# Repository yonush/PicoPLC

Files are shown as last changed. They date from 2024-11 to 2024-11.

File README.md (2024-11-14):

# The RP2040/RP2350 PLC - picoPLC

This repo is the design files and sample code for the diy PLC "picoPLC". It is robust PLC using the Raspberry Pi microcontroller boards as the main controller. Supported boards:

- Raspberry Pico (RP2040)
- Raspberry Pico W (RP2040)
- Raspberry Pico 2 (RP2350 using ARM cores)
- Raspberry Pico 2 (RP2350 using RISC-V cores)

Other RP2040/RP2350 boards that follow the Raspberry Pico pinout are also supported

The picoPLC has the following features 

- 5-12V power (connections are 12V tolerant. NO 24V)
- Has a 3.3, 5V and 12V breakout (if 12V power used)
- 8 digital outputs using relays
- 8 digital inputs
- 3 analog inputs
- 2 analog outputs (PWM or analog)
- 1 1-wire (Dallas/DHT22/DHT11, etc)
- 1 I2C, SPI, UART (shared pins)

The picoPLC was originally designed to use the [OpenPLC](https://autonomylogic.com/) soft PLC but it has been tested with C/C++, MicroPython and CircuitPython. Sample code for the CircuitPython has been included. The demo CircuitPython code uses [pyRTOS](https://github.com/Rybec/pyRTOS) as a proof of concept for some asynchronous tasks. 

### Mutli-core operation

Multi-core operation is not supported in CircuitPython but is available using MicroPython. Multi-core operation can be achieved in OpenPLC by editing the HAL source files and using the Mbed OS toolchain. More details on Using OpenPLC can be found in [OpenPLC Notes](OpenPLC_notes.md)

### TODO
- :white_check_mark: Fix PWM range and frequency (rev2)
- :white_large_square: Revision 3 to support 24V inputs
- :white_large_square: Revision 3 to include opto-isolaters on the inputs
- :white_large_square: Additional sample code

## Schematic
Schematic was created in KiCad. The BoM can be found in **Schematic and PCB** folder. The image below is only of page 1. Full schematic can be found in the folder.

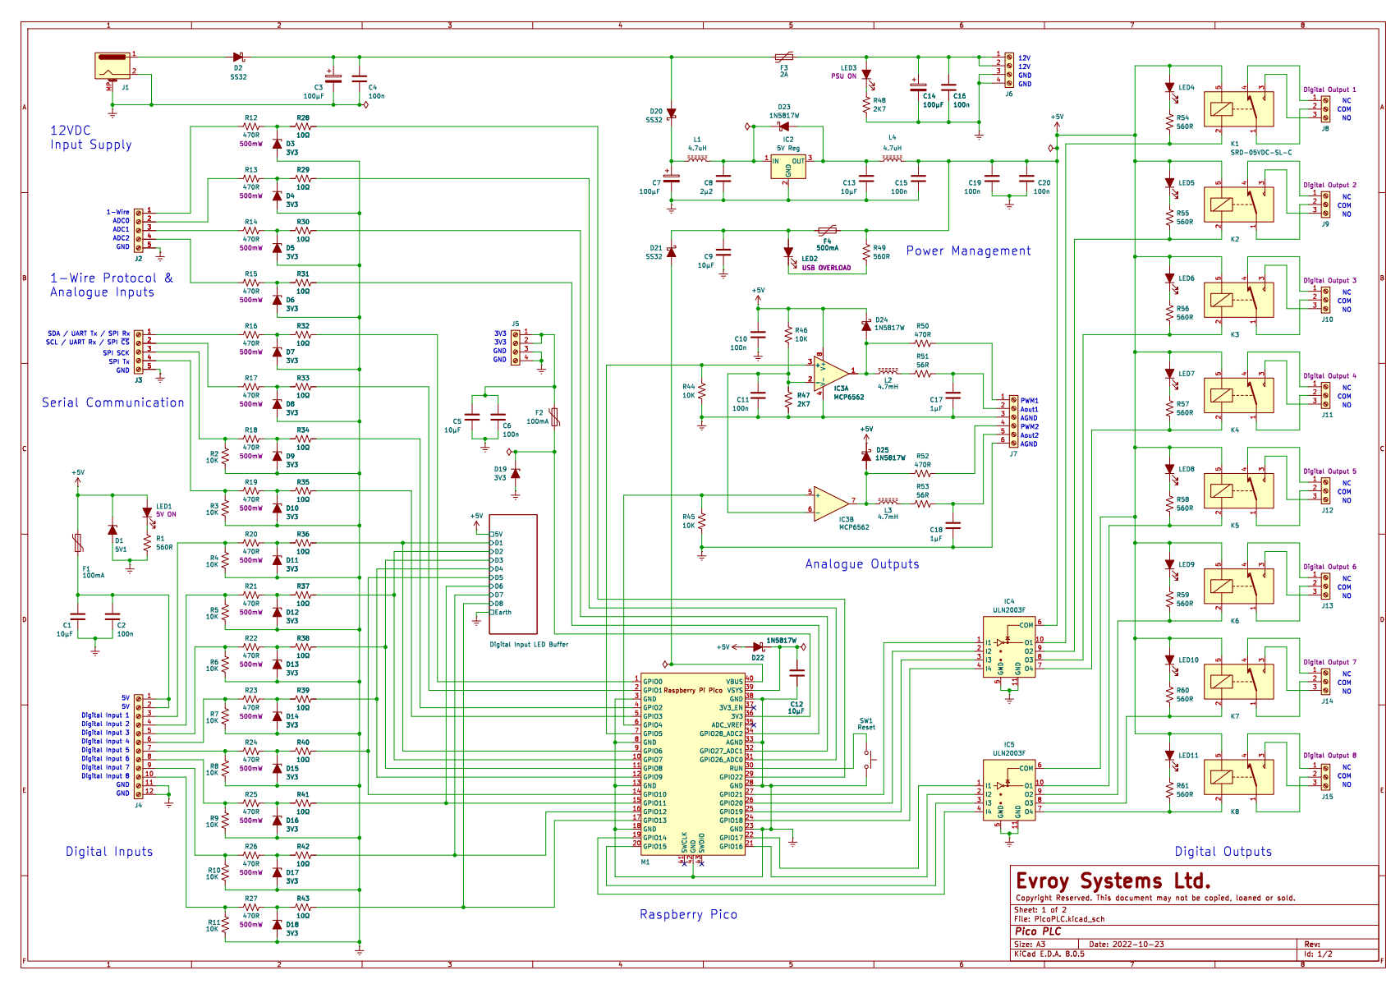
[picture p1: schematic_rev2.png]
schematic


### Physical device

**Revison 1**
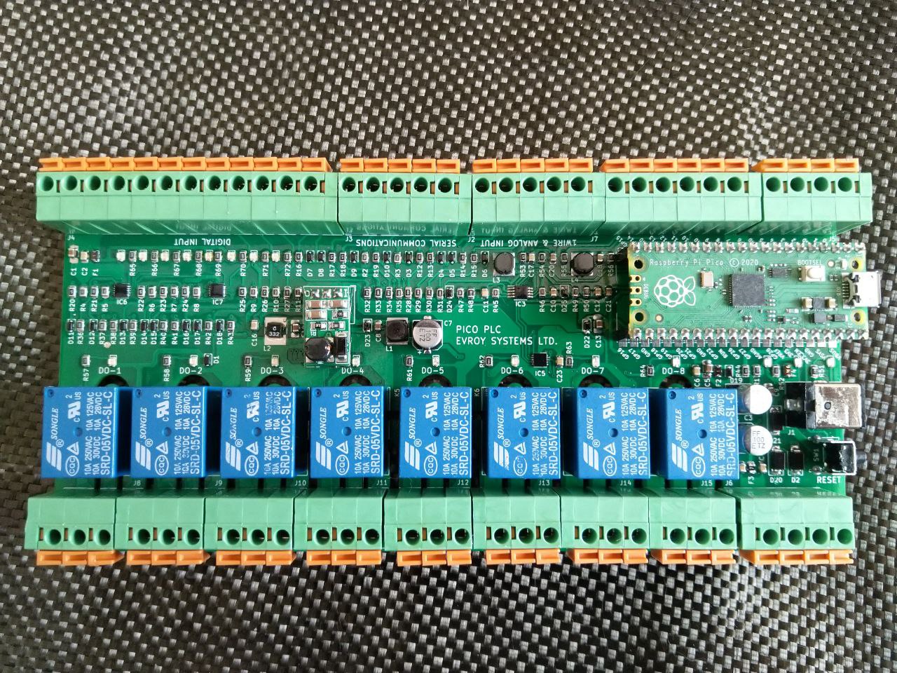
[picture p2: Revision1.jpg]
revision_1


**Revison 2**
reviison_2

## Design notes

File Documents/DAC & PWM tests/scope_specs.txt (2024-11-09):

Model:DS2302A
Manufacturer:RIGOL TECHNOLOGIES
Hardware Ver:2.0
Firmware:00.03.05.00.01
Status:
L:[HEX] 0000 0000	[BIN] 0000 0000 0000 0000 0000 0000 0000 0000
H:[HEX] 0000 0000	[BIN] 0000 0000 0000 0000 0000 0000 0000 0000
2023:2:6 20:48:43

	DSO Vertical System 
CH1:On
Scale:1.000e+03mV/
Position:-2.000e+03mV
Coupling:DC
Invert:Off
Bandwidth Limit:OFF
Probe Ratio:10X
Impedance:1M
Unit:V
User Cal:0ps

CH2:Off
Scale:1.000e+04mV/
Position:6.750e+04mV
Coupling:DC
Invert:Off
Bandwidth Limit:OFF
Probe Ratio:50X
Impedance:1M
Unit:V
User Cal:0ps

	DSO Horizontal System
Delay:Off
Time Vernier:Off
Time Mode:YT
Time Scale:1.000000e-03s
Delay Time Scale:5.000000e-04s
Time Offset:0.000000e+00s
Delay Time Offset:7.000000e-04s

	DSO Acquire System
Acquire Mode:Normal
Memory Depth:14000000
Average Num:2
Sampling Rate:1.000e+09

	DSO Normal Trigger System
Trigger Mode:Edge
Trigger Source:CH1
Trigger Sweep:Single
Trigger Coupling:DC
Trigger Noise Reject:Off
Trigger HoldOff:1.000000e-07s
CH1 Level:5.070000V
CH2 Level:-100.100000V
Ext Level:0.000000V
Trigger Edge Slope:Rising
Pulse Condition:Negative More Less
Pulse High:1.911204e-02s
Pulse Low:1.391204e-02s
Runt Polarity:Negative
Runt Condition:More
Windows Type:Alternate
Windows Pos:Enter
Window Time:1.000e-06s
NCycle Edge:Rise
NCycle Time:1.000e-07s
NCycle Num:2
Slope Condition:Positive More
Slope High:2.000e-06s
Slope Low:1.000e-06s
Slope Level1:1.020000V
Slope Level2:-4.000000V
Video Polarity:Negative
Video Sync:All Lines
Video Standard:NTSC
Video Line:1
Pattern HL:[HEX] 0000 0000	[BIN] 0000 0000 0000 0000 0000 0000 0000 0000
Pattern Mask:[HEX] 0000 0000	[BIN] 0000 0000 0000 0000 0000 0000 0000 0000
Pattern Edge:[HEX] 0000 0000	[BIN] 0000 0000 0000 0000 0000 0000 0000 0000
Pattern Edge Mask:[HEX] 0000 0000	[BIN] 0000 0000 0000 0000 0000 0000 0000 0000
Delay A:CH1
Delay B:CH2
Delay A Slope:Rising
Delay B Slope:Rising
Delay Range:More
Delay High:2.000e-06s
Delay Low:1.000e-06s
TimeOut Slope:Rising
TimeOut:1.000e-06s
Duration Type:More
Dura. High:2.000e-06s
Dura. Low:1.000e-06s
Setup/Hold Clk:CH1
Setup/Hold Data:CH2
Setup/Hold Slope:Rising
Setup/Hold Patt.:H
Setup/Hold Type:Setup
Setup Time:5.000e-08s
Hold Time:5.000e-08s

	DSO Advanced Trigger System
I2C Trigger
Clock Source:CH1
Data Source:CH2
I2C Type:Start
Address:1
Data Qualifier:Equal
Address Qualifier:Equal
Direction:Read
Address Length:7
Byte Length:1

Data:[HEX] 0000 0000 0000 0000	[BIN] 0000 0000 0000 0000 0000 0000 0000 0000 0000 0000 0000 0000 0000 0000 0000 0000
Mask:[HEX] 0000 0000 0000 0000	[BIN] 0000 0000 0000 0000 0000 0000 0000 0000 0000 0000 0000 0000 0000 0000 0000 0000

RS232 Trigger
RS232 Source:CH1
RS232 Type:Frame Start
RS232 Stop Bit:1
RS232 Parity:None
RS232 Data Bit:8
RS232 Baudrate:9600
RS232 User Baudrate:9600
RS232 Data:70

SPI Trigger
SCLK:CH1
SDA:CH2
Mode:Timeout
Edge:Rise
Timeout:1.000e-06
Data Length:8
Data:[HEX] 0000 0000	[BIN] 0000 0000 0000 0000 0000 0000 0000 0000
Mask:[HEX] 0000 0000	[BIN] 0000 0000 0000 0000 0000 0000 0000 0000

CAN Trigger
CAN Type:Start
Frame:Data
Signal:Rx
Speed:10K
User Speed(KB):50.000000
Sampling Point:50
Error:Bit Fill
Standard ID:true
Setting ID:false
Data Length:1
ID:1
Data:[HEX] 0000 0000 0000 0000	[BIN] 0000 0000 0000 0000 0000 0000 0000 0000 0000 0000 0000 0000 0000 0000 0000 0000
Data:[HEX] 0000 0000 0000 0000	[BIN] 0000 0000 0000 0000 0000 0000 0000 0000 0000 0000 0000 0000 0000 0000 0000 0000

USB Trigger
Type:SOP
DP:CH1
DN:CH2
Speed:Low

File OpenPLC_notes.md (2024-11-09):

# Notes on using OpenPLC with the Raspberry Pico 1, Pico W and Pico 2

Other variants of the pico board work too. This may require changes or additions to the editor\arduino\examples\Baremetal\hals.json file.

An additional .cpp & .hal file might be requried in the editor\arduino\src\hal folder to support new pico hardware.

## OpenPLC hal definitions for the Pico 1, Pico 1 W, and Pico 2

The Hardard 3 cores in the Pico 2 are also supported by OpenPLC

**Note, the mapping of the digital out pins in OpenPLC differ to the physical pins on the picoPLC.**

``` json
  "Raspberry Pico": {
    "core": "rp2040:rp2040",
    "default_ain": "26, 27, 28",
    "default_aout": "4,5",
    "default_din": "6, 7, 8, 9, 10, 11, 12, 13",
    "default_dout": "14, 15, 16, 17, 18, 19, 20, 21",
    "last_update": 0,
    "platform": "rp2040:rp2040:rpipico",
    "source": "rp2040pico.cpp",
    "version": "4.2.0"
  },
  "Raspberry Pico 2": {
    "core": "rp2040:rp2040",
    "default_ain": "26, 27, 28",
    "default_aout": "4,5",
    "default_din": "6, 7, 8, 9, 10, 11, 12, 13",
    "default_dout": "14, 15, 16, 17, 18, 19, 20, 21",
    "last_update": 0,
    "platform": "rp2040:rp2040:rpipico2",
    "source": "rp2040pico.cpp",
    "version": "4.2.0"
  },
  "Raspberry Pico 2 (RISCV)": {
    "arch": "riscv",
    "core": "rp2040:rp2040",
    "default_ain": "26, 27, 28",
    "default_aout": "4,5",
    "default_din": "6, 7, 8, 9, 10, 11, 12, 13",
    "default_dout": "14, 15, 16, 17, 18, 19, 20, 21",
    "last_update": 0,
    "platform": "rp2040:rp2040:rpipico2:arch=riscv",
    "source": "rp2040pico.cpp",
    "version": "4.2.0"
  },
  "Raspberry Pico W": {
    "core": "rp2040:rp2040",
    "default_ain": "26, 27, 28",
    "default_aout": "4,5",
    "default_din": "6, 7, 8, 9, 10, 11, 12, 13",
    "default_dout": "14, 15, 16, 17, 18, 19, 20, 21",
    "define": "BOARD_PICOW",
    "last_update": 0,
    "platform": "rp2040:rp2040:rpipicow",
    "source": "rp2040pico.cpp",
    "version": "4.2.0"
  },
```
## RP2040/RP2350 notes for the picoPLC pinout

Raspberry Pi Pico PINOUT (RP2040)
Digital In:  6, 7 ,8, 9, 10, 11, 12, 13     (%IX0.0 - %IX0.7)
Digital Out: 21, 20, 19, 18, 17, 16, 15, 14 (%QX0.0 - %QX0.7) (this is opposite to the list in OpenPLC)
Analog In: A1, A2, A3 (26,27,28)            (%IW0 - %IW2)
Analog Out: 4,5                             (%QW0 - %QW1)

The onboard LED (GPIO25) is not used but can be accessed from OpenPLC for the Pico or Pico 2 NOT the Pico W!!

## updated modbus addressing

The Modbus address space was expanded to include memory locations %MW (16-bit words) %MD (32-bit double words) and %ML (64-bit long words). These extra memory locations are available as Modbus holding registers. Here is the breakdown of the address space:
 
%QW0 - %QW31 -> Modbus holding registers 0 - 31
%MW0 - %MW19 -> Modbus holding registers 32 - 51
%MD0 - %MD19 -> Modbus holding registers 52 - 91 (each MD takes up two Modbus registers)
%ML0 - %ML19 -> Modbus holding registers 92 - 171 (each ML takes up four Modbus registers)
 
This means can also read/write REAL and LREAL variables on Modbus registers. You can locate the REAL variable on any %MD location or LREAL variable on any %ML location. Larger integers are also possible using these expanded locations. On the modbus master side, you just need to configure your application to concatenate Modbus registers to form an IEEE float (two registers in case of REAL or four registers in case of LREAL).

### Typical Modbus ranges
Discrete Output Coils      00001-09999
Discrete Input Contacts    10001-19999
Analog Input Registers     30001-39999
Holding Registers          40001-49999

The following location prefixes are supported:
    I for input
    Q for output
    M for memory

The following size prefixes are supported:

    X for bit (1 bit)
    B for byte (8 bits)
    W for word (16 bits)
    D for double word (32 bits)
    L for long word (64 bits)

The following are invalid examples of PLC addresses in OpenPLC for the stated reason:

    %IX0.8 The least significant index is greater than 7.
    %QX0.0.1 Three part hierarchy is not permitted address.
    %IB1.1 Two part hierarchy is only permitted for X data size.

### Modbus functions

OpenPLC supports the following Modbus functions:

    Read discrete output coil (0x01)
    Write discrete output coil (0x05)
    Write multiple discrete output coils (0x0F)
    Read discrete input contacts (0x02)
    Read analog input registers (0x04)
    Read analog output holding registers (0x03)
    Write analog output holding register (0x06)
    Write multiple analog output registers (0x10)

Discrete output coil and discrete input contact binding are based on the the two-part PLC address, without unused Modbus data addresses. The least-significant part of the PLC address has a range 0 to 7, therefore, a little math is needed to translate between PLC addresses and Modbus data addresses. Given the Modbus data address, the PLC address is determined as:

    msp := int(modbus_data_address / 8)
    lsp := modbus_data_address mod 8
    final address = msp.lsp

    For example, if the Modbus address for a discrete output coil is 22, then the most significant part is 2 (22 / 8) and the least significant part is 6 (22 mod 8). Therefore, the PLC address is %QX2.6.

## Avoiding the "error: implicit declaration of function" in OpenPLC

This error happens when you declare variables in the **Res0** file and not the **Program** file.

There are two toolchains that you can use in OpenPLC:

    Board FQBN: rp2040:rp2040:rpipico (currently used in OpenPLC)
    Board FQBN:- arduino:mbed_rp2040:pico

The #1 is from [earlephilhower on Github](https://github.com/earlephilhower/arduino-pico/) and #2 Arduino mbed toolchain.

The board types are set in the *editor\arduino\examples\Baremetal\hals.json* file.
If you compile your code with #1 you will get the "implicit declaration of function" because the code has moved from the POU.c to Res0.c and this compiler does not like you using functions before declaring them. The globals can be moved to the project. If you use the #2 toolcahain then the error disappears. I have not found a safer way of solving the Res0 issue.
 
Using the following will be required to install the additional toolchain. the bin can be found in the 
editor\arduino\bin or downloaded directly from [arduino-cli](https://arduino.github.io/arduino-cli/1.1/installation/#latest-packages)
``` sh
arduino-cli-w64.exe core install arduino:mbed_rp2040
```

## Research
Tangible Learning for IoT and Automation ... in a Lunchbox

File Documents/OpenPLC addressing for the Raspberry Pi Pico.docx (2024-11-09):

# OpenPLC Modbus addresses bind to PLC addresses based on the hierarchical address value

Modbus Data Type | Usage | PLC Address | Modbus Data Address | RP2040 Modbus addressing | Data Size | Range | Access
Discrete Output Coils | Digital Outputs | %QX0.0 – %QX99.7 | 0 – 799 | 0 – 55 | 1 bit | 0 or 1 | RW
Discrete Output Coils | Slave Outputs | %QX100.0 – %QX199.7 | 800 – 1599 | 56 – 156 | 1 bit | 0 or 1 | RW
Discrete Input Contacts | Digital Inputs | %IX0.0 – %IX99.7 | 0 – 799 | 0 – 55 | 1 bit | 0 or 1 | R
Discrete Input Contacts | Slave Inputs | %IX100.0 – %IX199.7 | 800 – 1599 | 56 – 156 | 1 bit | 0 or 1 | RW
Analog Input Registers | Analog Input (including slave) | %IW0 – %IW1023 | 0 – 1023 | 0 – 32 | 16 bits | 0 – 65535 | R
Holding Registers | Analog Outputs (including slave) | %QW0 – %QW1023 | 0 – 1023 | 0 – 32 | 16 bits | 0 – 65535 | RW
Holding Registers | Memory (16-bits) | %MW0 – %MW1023 | 1024 – 2048 | 33 – 52 | 16 bits | 0 – 65535 | RW
Holding Registers | Memory (32-bits) | %MD0 – %MD1023 | 2048 – 4095 | 53 – 92 | 32 bits | 0 – 4294967295 | RW
Holding Registers | Memory (64-bits) | %ML0 – %ML1023 | 4096 – 8191 | 93 –172 | 64 bits | 0 – 2⁶⁴ | RW

Due to memory limitations, microcontroller-based platforms the RP2040/RP2350 have a much more limited Modbus address space, according to the table below

# Raspberry Pi Pico, Pico W, Pico 2 addressing for the OpenPLC

Modbus Data Type | Usage | Pico GPIO pin | PLC address
Discrete Output Coils | Digital Outputs | | %QX100.0 - %QX100.7
Discrete Output Coils | Slave Outputs | 21, 20, 19, 18, 17, 16, 15, 14 | %QX0.0 - %QX0.7
Discrete Input Contacts | Digital Inputs | | %IX100.0 - %IX100.7
Discrete Input Contacts | Slave Inputs | 6, 7, 8, 9, 10, 11, 12, 13 | %IX0.0 - %IX0.7
Analog Input Registers | Analog Input (including slave) | A1, A2, A3 (26,27,28) | %IW0 - %IW2
Holding Registers | Analog Outputs (including slave) | 4,5 | %QW0 - %QW1

# Additional pin functionality on the Raspberry Pi Pico, Pico W, Pico 2 with CircuitPython/MicroPython and NOT OpenPLC

Dallas 1-Wire serial protocol or DHT11/22 | GP22
I2C | SDA GP0, SCL GP1 | Can be mapped as GPIO
SPI | SPI0 RX GP0, SPI0 CS GP1, SPI0 SCK GP2, SPI0 TX GP3 | Can be mapped as GPIO
UART | UART0 TX GP0, UART0 RX GP1 | Can be mapped as GPIO

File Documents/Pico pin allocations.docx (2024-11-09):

/******************PINOUT CONFIGURATION***********************

Digital In: 6, 7, 8, 9, 10, 11, 12, 13 (%IX0.0 - %IX0.7)

Digital Out: 21, 20, 19, 18, 17, 16, 15, 14 (%QX0.0 - %QX0.7)

Analog In: A1, A2, A3 (26,27,28) (%IW0 - %IW2)

Analog Out: 5, 4 (%QW0 - %QW1)

**************************************************************/

1-Wire serial protocol is on GPIO22

I2C SDA/UART Tx/SPI Rx on GPIO0

I2C SCL/UART Rx/SPI CS on GPIO1

SPI SCK on GPIO2

SPI Tx on GPIO3

What of “dual purpose” pins (eg analogue outputs can also be configured as digital outputs, SPI SCK and SPI Tx as digital inputs

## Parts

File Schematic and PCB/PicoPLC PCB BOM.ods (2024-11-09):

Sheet: PicoPLC_PCB
Pico PLC PCB Bill of Materials
Description | Part Number | Package | Quantity | Unit Cost | Total Cost | Supplier | Second Source | Fitted by PCBWay | Price Breakpoint | Comment
Capacitor 100nF 50V X7R | C0805C104M5RACAUTO | 0805 | 9 | $0.05 | $0.41 | Digikey (https://www.digikey.co.nz/en/products/detail/kemet/C0805C104M5RACAUTO/5762233) |  | Y | 100
Capacitor 1uF X7R | CL21B105KOFVPNE | 0805 | 2 | $0.99 | $1.98 | Digikey (https://www.digikey.co.nz/en/products/detail/samsung-electro-mechanics/CL21B105KOFVPNE/5961331) |  | Y | 50
Capacitor 2.2uF 25V X7R | TMK212B7225KGHT | 0805 | 1 | $0.09 | $0.09 | Digikey (https://www.digikey.co.nz/en/products/detail/taiyo-yuden/TMK212B7225KGHT/4157474) | AliExpress (https://www.aliexpress.com/item/1005002969360447.html) | Y | 100
Capacitor 10uF 16V X7R | CGA5L1X7R1C106M160AC | 1206 | 5 | $0.17 | $0.83 | Digikey (https://www.digikey.co.nz/en/products/detail/tdk-corporation/CGA5L1X7R1C106M160AC/3950139) | AliExpress (https://www.aliexpress.com/item/1005002969586020.html) | Y
Capacitor Elec 100uF 25V 6.30mm Diameter | 25TZV100M6.3X8 | 6.6mm x 6.6mm | 3 | $0.61 | $1.82 | Digikey (https://www.digikey.co.nz/en/products/detail/rubycon/25TZV100M6-3X8/3134865) |  | Y | 100
Connector Barrel Jack 2.0mm ID / 5.5mm OD | PJ-063AH |  | 1 | $2.88 | $2.88 | Digikey (https://www.digikey.co.nz/en/products/detail/cui-devices/PJ-063AH/2161208)
Connector spring loaded terminal 3 way | 142V-5.08 (3 Pole) |  | 8 | $0.58 | $4.64 | AliExpress (https://www.aliexpress.com/item/1005004101847243.html) |  |  | 50 | Delivery cost based on delivery of 10 parts only.
Connector spring loaded terminal 4 way | 142V-5.08 (4 Pole) |  | 2 | $0.84 | $1.68 | AliExpress (https://www.aliexpress.com/item/1005004101847243.html) |  |  | 50 | Delivery cost based on delivery of 10 parts only.
Connector spring loaded terminal 5 way | 142V-5.08 (5 Pole) |  | 2 | $1.11 | $2.22 | AliExpress (https://www.aliexpress.com/item/1005004101847243.html) |  |  | 50 | Delivery cost based on delivery of 10 parts only.
Connector spring loaded terminal 6 way | 142V-5.08 (6 Pole) |  | 1 | $0.92 | $0.92 | AliExpress (https://www.aliexpress.com/item/1005004101847243.html) |  |  | 50
Connector spring loaded terminal 12 way | 142V-5.08 (12 Pole) |  | 1 | $1.67 | $1.67 | LCSC Elec. (https://lcsc.com/product-detail/Spring-Clamp-System-Terminal-Block_Cixi-Kefa-Elec-KF142V-5-08-12P_C475143.html) | AliExpress (https://www.aliexpress.com/item/1005004101847243.html) |  | 50 | Delivery cost based on delivery of 10 parts only.
Diode LED 0805 35mcd Green |  | 0805 | 16 | $0.07 | $1.05 |  | AliExpress (https://www.aliexpress.com/item/1005003112067589.html) | Y | 100
Diode LED 0805 35mcd Red |  | 0805 | 3 | $0.07 | $0.20 |  | AliExpress (https://www.aliexpress.com/item/1005003112067589.html) | Y | 100
Diode Schottky 40V 500mA | SD0805S040S0R5 / 1N5817W | SOD-123FL | 4 | $0.38 | $1.52 | Digikey (https://www.digikey.co.nz/en/products/detail/kyocera-avx/SD0805S040S0R5/3749489) | AliExpress 1N5817W (https://www.aliexpress.com/item/1005003136168815.html) | Y | 100 | datasheet (https://www.smc-diodes.com/propdf/1N5817W-1N5819W%20N1756%20REV.-.pdf)
Diode Schottky 40V 3A | CDBA340-HF (SS32) | DO-214C | 3 | $0.02 | $0.07 | Digikey (https://www.digikey.co.nz/en/products/detail/micro-commercial-co/SL14A-TP/7652328) | AliExpress SS32 (https://www.aliexpress.com/item/1005004401415364.html) | Y | 100
Diode Zener 3V3 500mW 40W surge SOD-123 | BZT52C3V3-TP | SOD-123 | 17 | $0.17 | $2.85 | Mouser (https://nz.mouser.com/ProductDetail/Micro-Commercial-Components-MCC/BZT52C3V3-TP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) | LCSC (https://www.lcsc.com/product-detail/Zener-Diodes_PANJIT-International-MMSZ5226B_R1_00001_C282311.html) | Y | 100
Diode Zener 5V1 500mW 40W surge SOD-123 | MMSZ4689-TP | SOD-123 | 1 | $0.54 | $0.54 | Mouser (https://nz.mouser.com/ProductDetail/Micro-Commercial-Components-MCC/MMSZ4689-TP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) | LCSC (https://www.lcsc.com/product-detail/Zener-Diodes_Diodes-Incorporated-MMSZ5231B-7-F_C85181.html) | Y | 100
Fuse Poly 100mA 0805 | 0ZCK0010FF2G |  | 2 | $0.24 | $0.49 | Mouser (https://nz.mouser.com/ProductDetail/530-0ZCK0010FF2G) | AliExpress (https://www.aliexpress.com/item/1005003192270354.html) | Y | 100
Fuse Poly 500mA 0805 | 0ZCK0050FF2E |  | 1 | $0.40 | $0.40 | Mouser (https://nz.mouser.com/ProductDetail/Bel-Fuse/0ZCK0050FF2E?qs=SRYZG9HaIQ3gw527qS%252BJNw%3D%3D) | AliExpress (https://www.aliexpress.com/item/1005003192270354.html) | Y | 10
Fuse Poly 1.5A 2920 | 2920L200/24DR |  | 1 | $1.37 | $1.37 | Mouser (https://nz.mouser.com/ProductDetail/Littelfuse/2920L200-24DR?qs=PWhpLWeW8wffSOrwZt6C2Q%3D%3D) |  | Y | 10 | Fuse is presently 0805. Update board for larger footprint if required
IC Comparator CMOS Push-Pull | MCP6562-E/MS |  | 1 | $1.17 | $1.17 | Digikey (https://www.digikey.co.nz/en/products/detail/microchip-technology/MCP6562-E-MS/1680912) |  | Y | 25 | For prototypes MCP1642 were used. Works but fails to supply accurate duty cycle at high frequency PWM due to substantial propagation delay of 4us.
IC Relay Driver | ULN2003F12FN-7 | U-DFN3030-10 | 4 | $0.75 | $2.98 | Digikey (https://www.digikey.co.nz/en/products/detail/diodes-incorporated/ULN2003F12FN-7/5054226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) |  | Y | 100
Inductor 4.7uH mA 60mΩ 2.7A | SRN5020TA-5R6M |  | 2 | $0.60 | $1.19 | Digikey (https://www.digikey.co.nz/en/products/detail/bourns-inc/SRN5020TA-4R7M/9653858) |  | Y | 100
Inductor 4.7mH 40mA 48Ω | SDR0503-103JL |  | 2 | $1.09 | $2.18 | Digikey (https://www.digikey.co.nz/en/products/detail/bourns-inc/SDR0503-472JL/2352799) |  | Y | 10
Mech Foam support 6mmx6mm | 6mmx6mm Silicone Foam |  | 0.36 | $1.49 | $0.54 | AliExpress (https://www.aliexpress.com/item/1005002726218504.html) |  |  | 5 | cost per linear meter
Mech Mounting plate Aluminium |  |  | 1 |  |  | QC Engineering | PCBWay |  | 10
Mech Standoff Nylon M3 x 6mm | M3x6mm | 4mm NPTH | 3 | $0.16 | $0.48 | AliExpress (https://www.aliexpress.com/item/1005001452726368.html) |  |  | 125
Mech Standoff Stainless M3 x 6mm female/male (6mm male thread) | M3 Plus 6 - 6mm | 3mm PTH pad | 1 | $0.45 | $0.45 | AliExpress (https://www.aliexpress.com/item/1005007208807217.html) |  |  | 100
Mech Standoff Stainless SEM Screw M3 x 5mm | M3 5mm |  | 1 | $0.11 | $0.11 | AliExpress (https://www.aliexpress.com/item/1005003105938745.html) |  |  | 50
Mech M3 Nut Stainless | M3 |  | 1 | $0.07 | $0.07 | AliExpress (https://www.aliexpress.com/item/1005003111431468.html) |  |  | 50
Mech M3 Spring Washer Stainless | M3 |  | 1 | $0.04 | $0.04 | AliExpress (https://www.aliexpress.com/item/1005003111259973.html) |  |  | 100
PCB 2 layer |  |  | 1 |  |  | PCB Way |  | Y | 5 | Price includes shipping
PSU DC/DC converter 7V – 40V/5V 1A | R-785.0-1.0 |  | 1 | $2.71 | $2.71 | Digikey (https://www.digikey.co.nz/en/products/detail/recom-power/R-785-0-1-0/2256218) | AliExpress (https://www.aliexpress.com/item/1005006132097041.html) |  | 10 | Price is for AliExpress module
Relay 5V 10A/230V Form C | SRD-05VDC-SL-C |  | 8 | $0.79 | $6.32 | AliExpress (https://www.aliexpress.com/item/1005001994042589.html) |  |  | 10
Resistor 0805 1/8W 10R | RMCF0805JT10R0 | 0805 | 16 | $0.01 | $0.12 | Digikey (https://www.digikey.co.nz/en/products/detail/stackpole-electronics-inc/RMCF0805JT1R00/1757812) | AliExpress (https://www.aliexpress.com/item/1005003268363806.html) | Y | 100
Resistor 0805 1/8W 56R | RMCF0805FT56R0 | 0805 | 2 | $0.01 | $0.02 | Digikey (https://www.digikey.co.nz/en/products/detail/stackpole-electronics-inc/RMCF0805FT56R0/1760260) | AliExpress (https://www.aliexpress.com/item/1005003268363806.html) | Y | 100
Resistor 0805 0.5W 470R | ERJ-P06J471V | 0805 | 19 | $0.07 | $1.38 | Digikey (https://www.digikey.co.nz/en/products/detail/panasonic-electronic-components/ERJ-P06J471V/525276) |  | Y | 100
Resistor 0805 1/8W 1% 560R | RMCF0805FT560R | 0805 | 17 | $0.01 | $0.16 | Digikey (https://www.digikey.co.nz/en/products/detail/stackpole-electronics-inc/RMCF0805FT560R/1713239) | AliExpress (https://www.aliexpress.com/item/1005003269950130.html) | Y | 100
Resistor 0805 1/8W 1% 2K7 | RMCF0805FT2K70 | 0805 | 2 | $0.01 | $0.02 | Digikey (https://www.digikey.co.nz/en/products/detail/stackpole-electronics-inc/RMCF0805FT10K0/1760676) | AliExpress (https://www.aliexpress.com/item/1005003269950130.html) | Y | 100
Resistor 0805 1/8W 1% 10K | RMCF0805FT10K0 | 0805 | 13 | $0.01 | $0.13 | Digikey (https://www.digikey.co.nz/en/products/detail/stackpole-electronics-inc/RMCF0805FT10K0/1760676) | AliExpress (https://www.aliexpress.com/item/1005003268363806.html) | Y | 100
Socket pin connector 2.54mm Vertical 20 pin Short |  |  | 2 | $0.35 | $0.70 | AliExpress (https://www.aliexpress.com/item/32854239374.html)
Socket pin male connector (Short) 20 pin |  |  | 2
Switch tactile right-angle 7mm actuator length | 1-1825027-2 |  | 1 | $0.22 | $0.22 | Digikey (https://www.digikey.co.nz/en/products/detail/te-connectivity-alcoswitch-switches/1-1825027-2/5401296) | AliExpress (https://www.aliexpress.com/item/32912894177.html) |  | 100
Pico-W PCB (RP2040) with Wifi |  |  | 1 | $11.98 | $11.98 | PBTech New Zealand (https://www.pbtech.co.nz/product/SEVRBP0335/Raspberry-Pi-Kit-Pack-Microcontrollers-Board---Pic)
PCB Assembly as per PCB Way Quote |  |  | 1 |  |  |  |  |  | 20 | Cost drops to 18.50 for 50 boards
Conformal coat |  |  | 1
 |  |  |  | TOTAL | $60.58
USB (Micro-USB) cable for programming and power. |  |  | 1

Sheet: PCB Errata
PCB ERRATA
Description | Comment | Resolution
5V1 and 3V1 footprint | currently using SOD-323 footprint. Consider replacing with SOD-123 footprint (slightly larger) as this is far more commonly available off AE etc.
2A PolyFuse | Footprint undersize on board. Increase size
Barrel Jack | Barrel jack could be replaced with lower cost option off AE (3 pin)
C1 C5 C9 C13 C14 – 10uF Wrong footprint | All 10uF caps should be 0805
1N5817 is not 0805 | Update footprint accordingly (either use an 0805 diode, or replace footprint)
Labels for RED LED’s | Mark what the LED’s are for (12V, OVL, 5V)
Reduce hole size for relays | if possible.
Reduce hole size for terminals | if possible.
Pull up resistors | Add pull up resistors to the clock/data lines for I2C and 1-WIRE. Internal pullups are too weak!
Pull up resistor 4k7 | Add pull up resistor for data line for 1 wire digital input
Normalize ADC voltage | Normalize and test to 3.3V
F3 Fuse wrong footprint | Used 1.5A 0805 from AliExpress, but larger fuse footprint may be required for given voltage.
Check option to run from up to 24V DC continuous (will need to upgrade 25V caps to 35V) and DC/DC converter spec check
Cut R49/R50/C12 out of circuit and use reference from IC3A/C11
Non linearity in ADC input voltage | the Pico ADC input voltage range = 0 – 3.3V. Unfortunately the zener diode starts clamping at about 2.7V, drawing approximately 1mA when ADC input = 3.3V. This causes the upper end of the voltage to be measured in a non linear manner. Need to modify the circuit such that it isn’t loaded by the zener, but at the same time is adequately protected.
Onboard 5V SMPSU

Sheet: DAC Filter
DAC Filter Test Results
 |  |  |  | F | Duty cycle
Description | Comment | Resolution
 |  |  |  | 0.1 | 32768
 |  |  |  | 0.2 | 32768
 |  |  |  | 0.3 | 32768
 |  |  |  | 0.4 | 32810
 |  |  |  | 0.5 | 32810
 |  |  |  | 1 | 32900
 |  |  |  | 2 | 33000
 |  |  |  | 3 | 33170
 |  |  |  | 4 | 33210
 |  |  |  | 5 | 33600
 |  |  |  | 10 | 35700
 |  |  |  | 20 | 39500 | Exact 50%
 |  |  |  | 30 | 42240
 |  |  |  | 40 | 45500
 |  |  |  | 50 | 48700
 |  |  |  | 75 | 55500
 |  |  |  | 100 | 62700
 |  |  | Difference | 29890
 |  |  | 99700
 |  |  | Factor | 0.299799398194584
 |  |  | Test value | 50000
 |  |  |  | 47608.0702106319

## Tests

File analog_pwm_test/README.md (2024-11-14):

# Analog out as PWM tests on the RP2040 for OpenPLC #

- In OpenPLC the pico analog_out accepts values from 0-65535 for a full PWM range which is then converted internally to 0-100.
- The PWM_CONTROLLER uses values 0-100 for the full PWM.

The OpenPLC driver code uses the Arduino library [RP2040_PWM](https://github.com/khoih-prog/RP2040_PWM).

## The PWM test
This folder contains an OpenPlC test project (picotest) to test the PWM analog out. The [rp2040pico.cpp](rp2040pico.cpp) is the driver file that has been updatde and should be in the current OpenPLC build as of 15 Nov 2024.

Testing was conducted on a Raspberry Pico 1 (RP2040)

You can use the analog out as a normal pin running PWM at a default of 10KHz (frequency set in the above code).

You can also use the PWM_CONTROLLER block to alter the PWM frequency other than the default 10KHz.

During the testing the pico IO was configured as follows
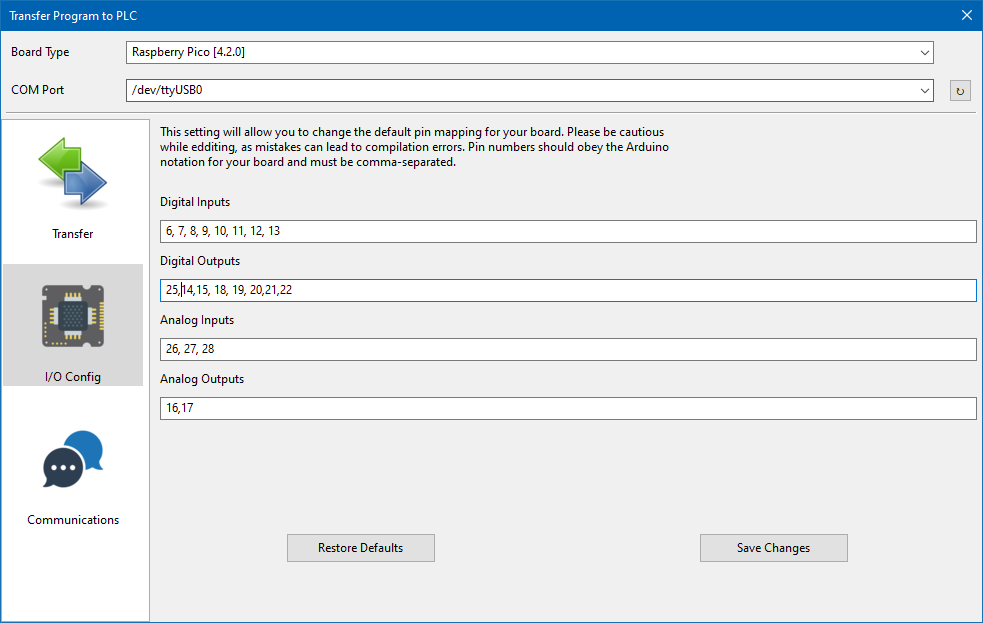
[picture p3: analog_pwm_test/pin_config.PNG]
config


Two LEDS were attached to GPIO16 (as %QW0) & GPIO17 (channel 1 on the PWM_CONTROLLER) with GPIO25 for the onboard LED.

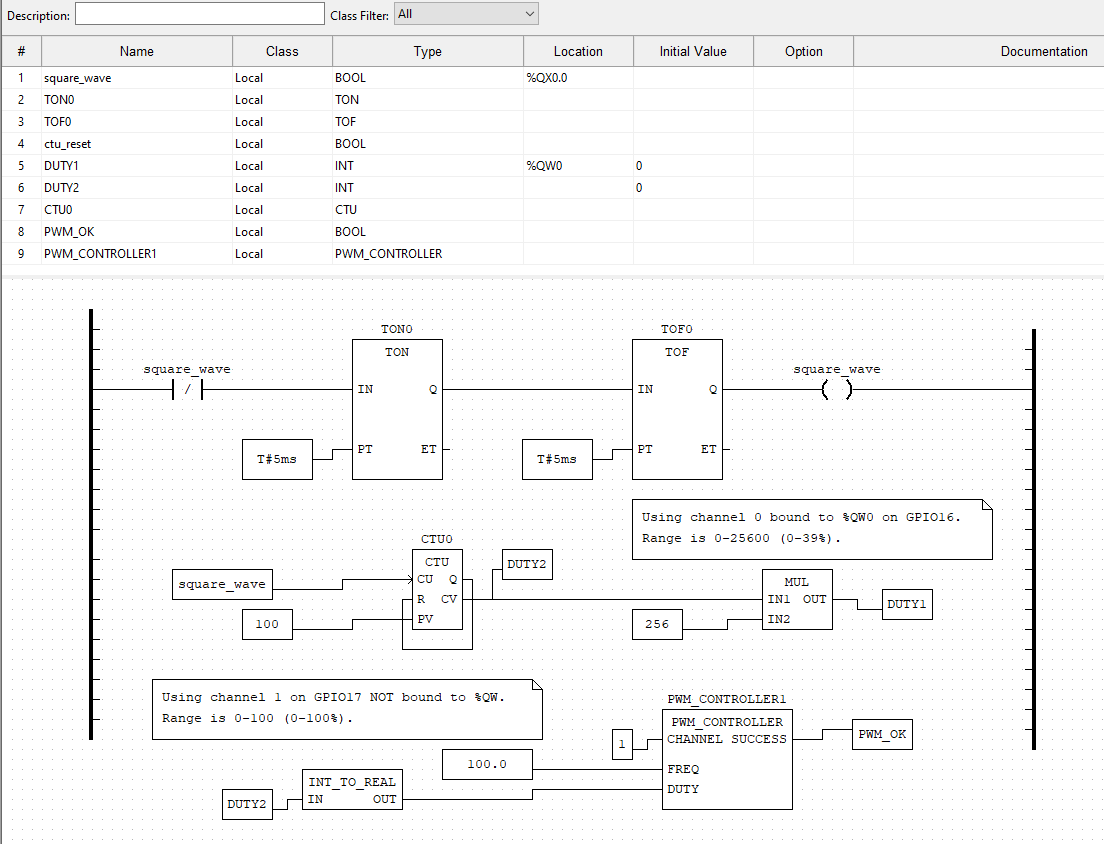
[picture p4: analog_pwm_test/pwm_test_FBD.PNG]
FDB


The testing
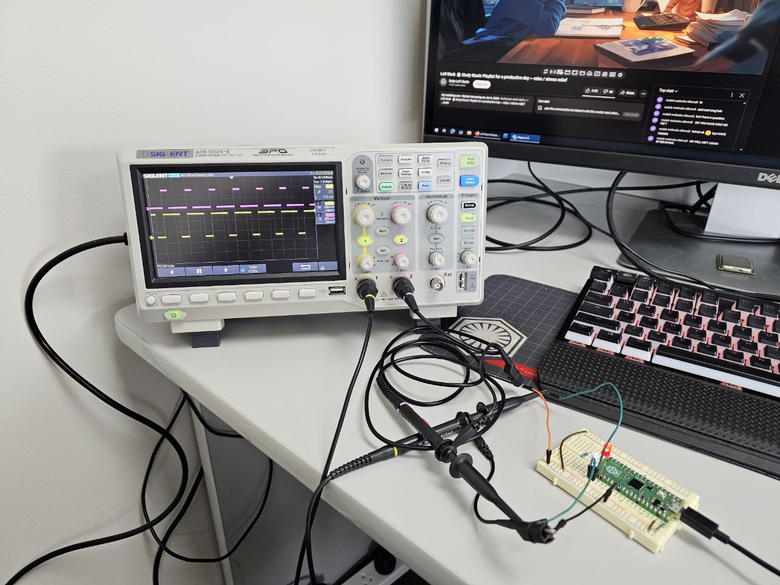
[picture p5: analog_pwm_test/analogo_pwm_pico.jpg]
test

Video of the two waveforms

video

-end-of-file-

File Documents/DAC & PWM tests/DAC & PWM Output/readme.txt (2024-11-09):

Filter Design
Final outcome and test of Analogue Output and PWM Output
Date: 29 September 2024

LCR filter components: 4.7mH, 1uF, 56R

Oscillograms show results as measured for PWM frequencies of 10kHz, 25kHz and 50kHz

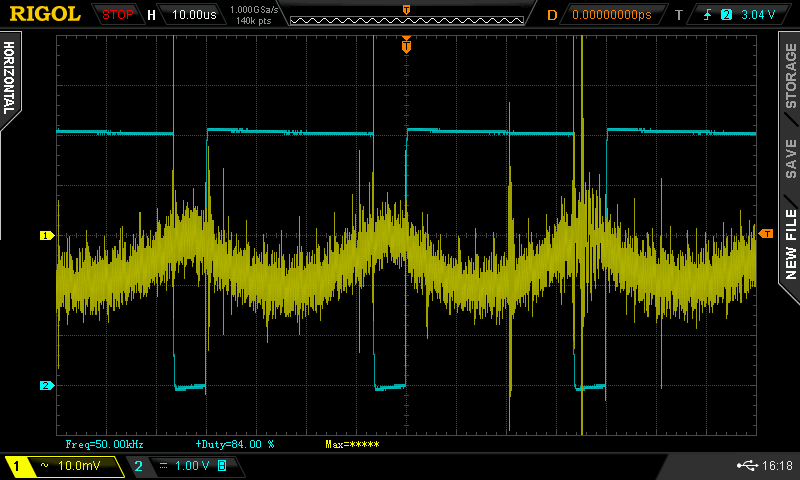
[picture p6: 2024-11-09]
Documents/DAC & PWM tests/DAC & PWM Output/50kHz/AC Ripple - 84 Percent Dutycycle.png

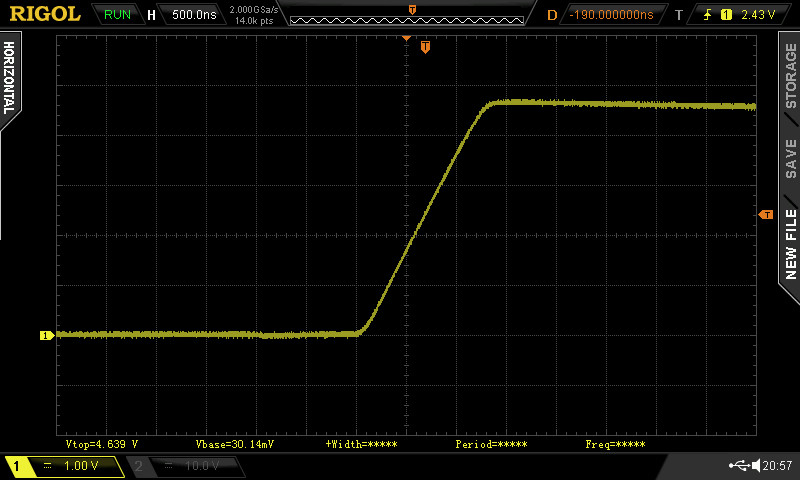
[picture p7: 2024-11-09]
Documents/DAC & PWM tests/Rising edge 2.jpeg

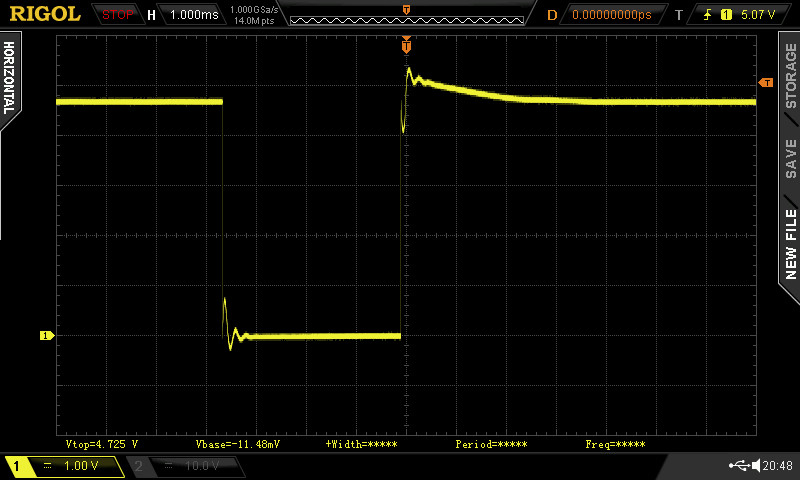
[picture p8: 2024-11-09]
Documents/DAC & PWM tests/5V blip on rising edge.jpeg

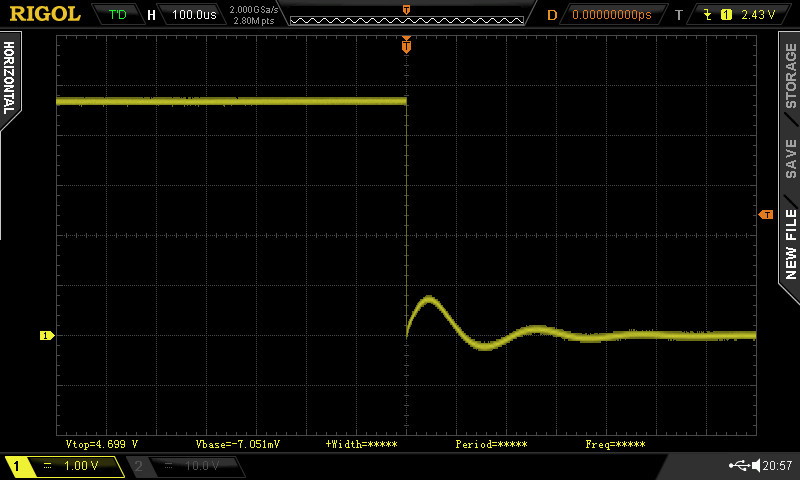
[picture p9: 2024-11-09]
Documents/DAC & PWM tests/falling edge 1.jpeg

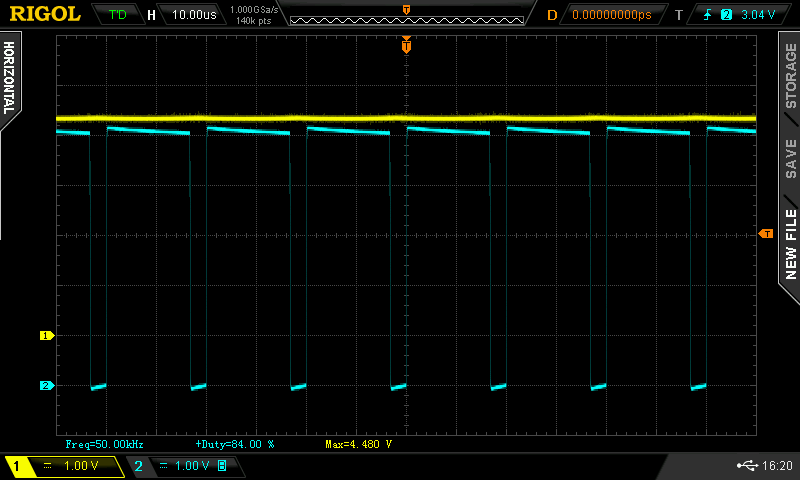
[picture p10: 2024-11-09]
Documents/DAC & PWM tests/DAC & PWM Output/50kHz/84 Percent Dutycycle.png

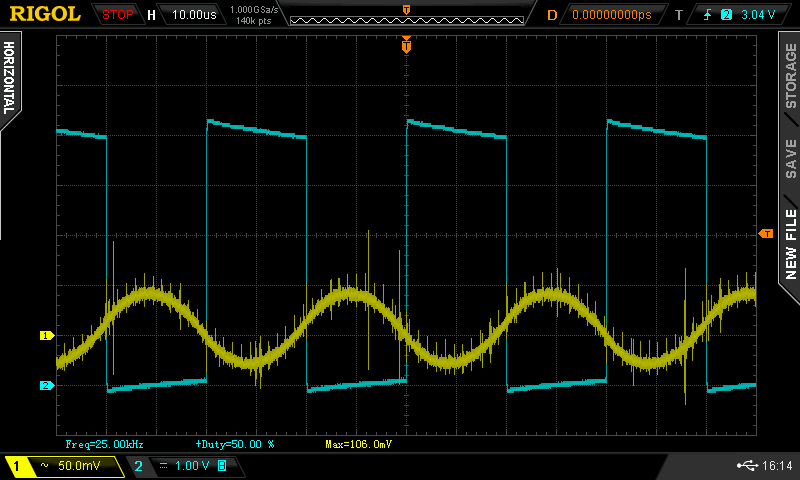
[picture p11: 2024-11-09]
Documents/DAC & PWM tests/DAC & PWM Output/25kHz/AC Ripple - 50 Percent Dutycycle.png

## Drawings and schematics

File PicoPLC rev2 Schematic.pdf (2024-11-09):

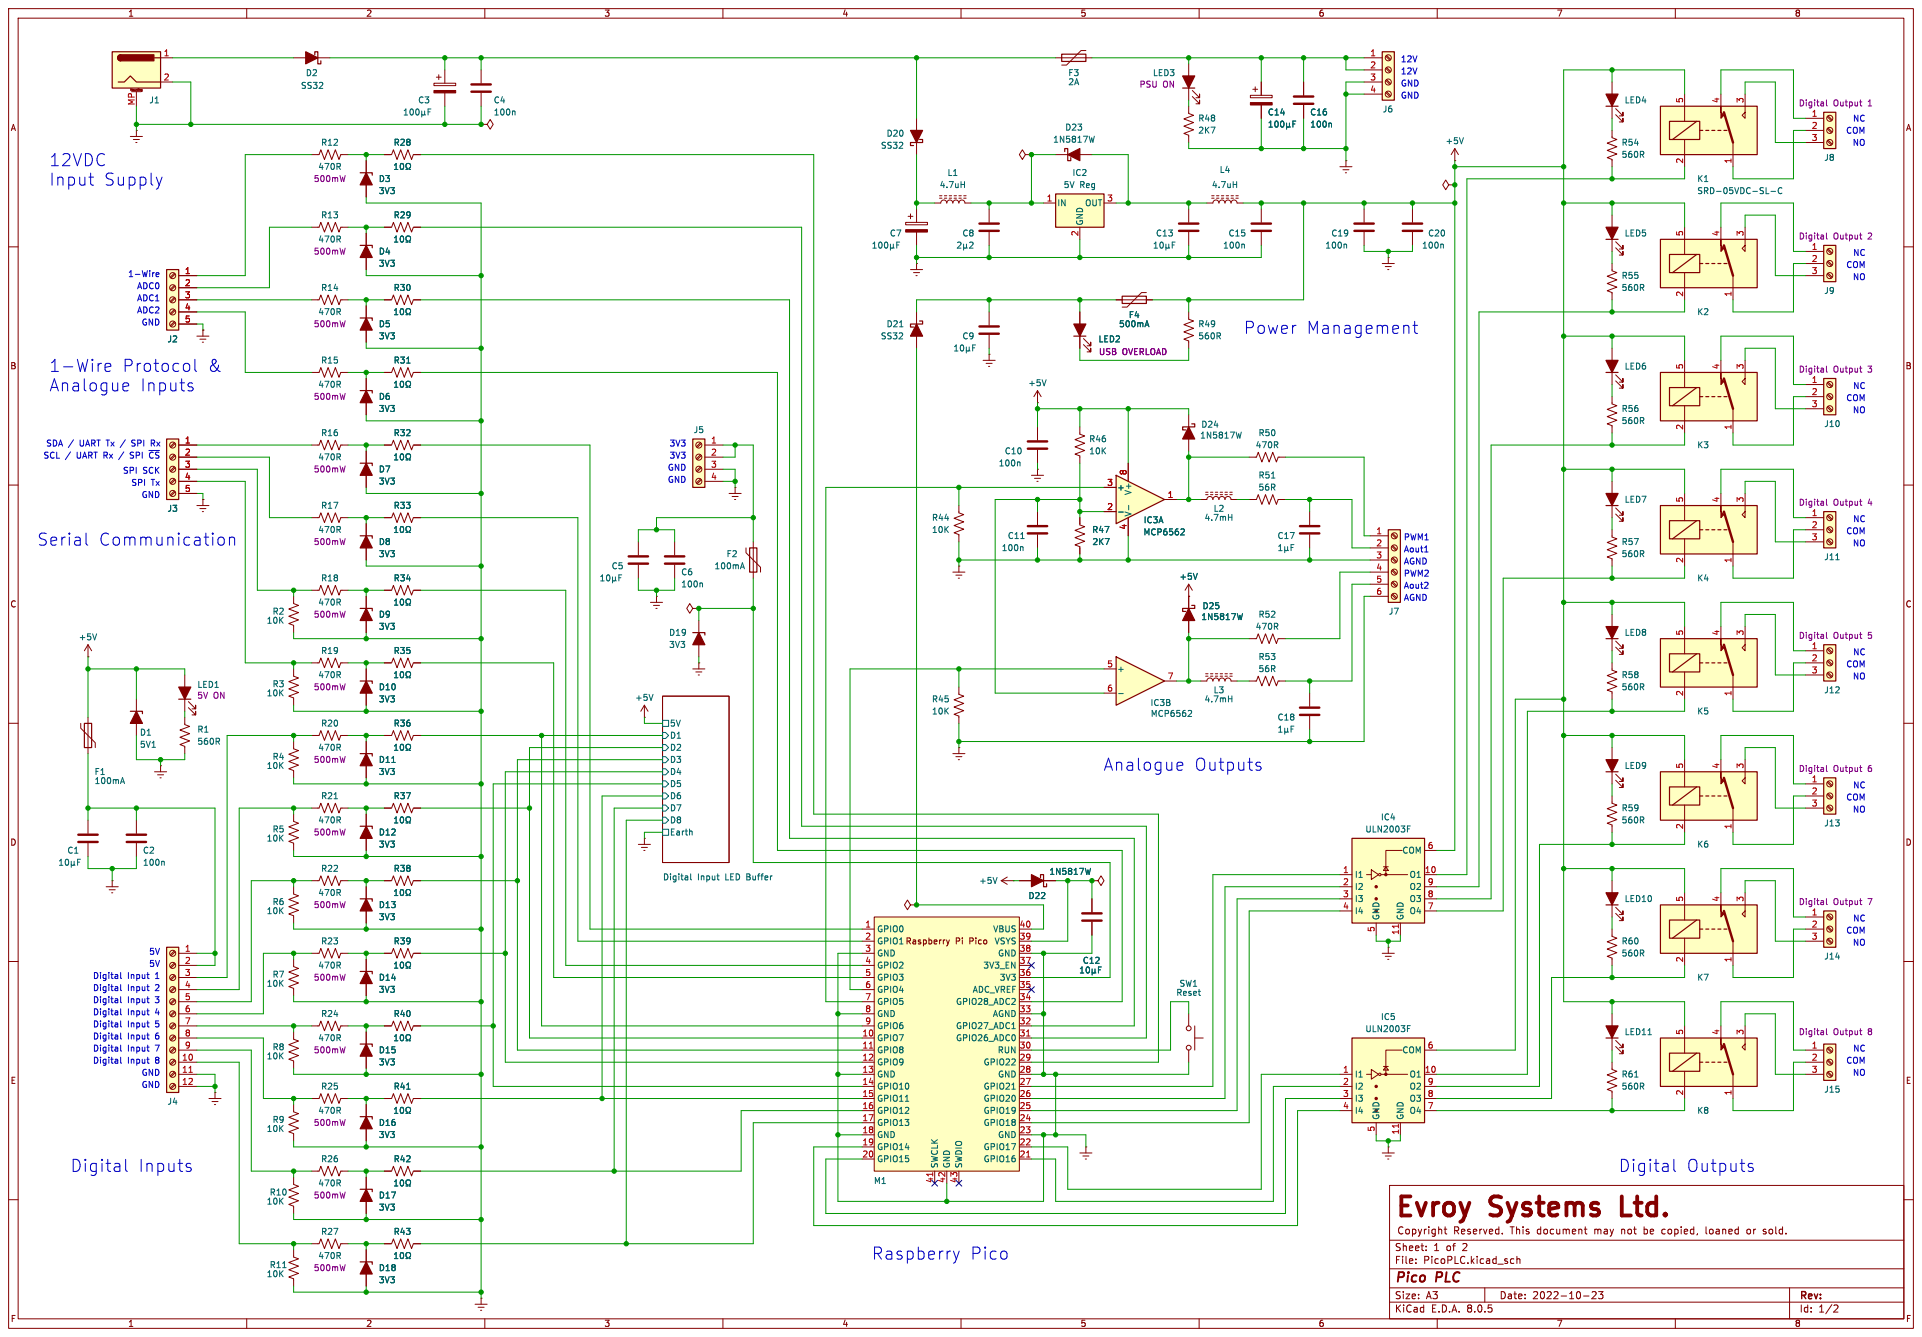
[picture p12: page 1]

1-Wire
SDA / UART Tx / SPI Rx Digital Input 1 Serial Communication
SCL / UART Rx / SPI ~{CS}

5V Digital Input 2 Digital Input 4 Digital Inputs

Digital Input 5 Digital Input 6

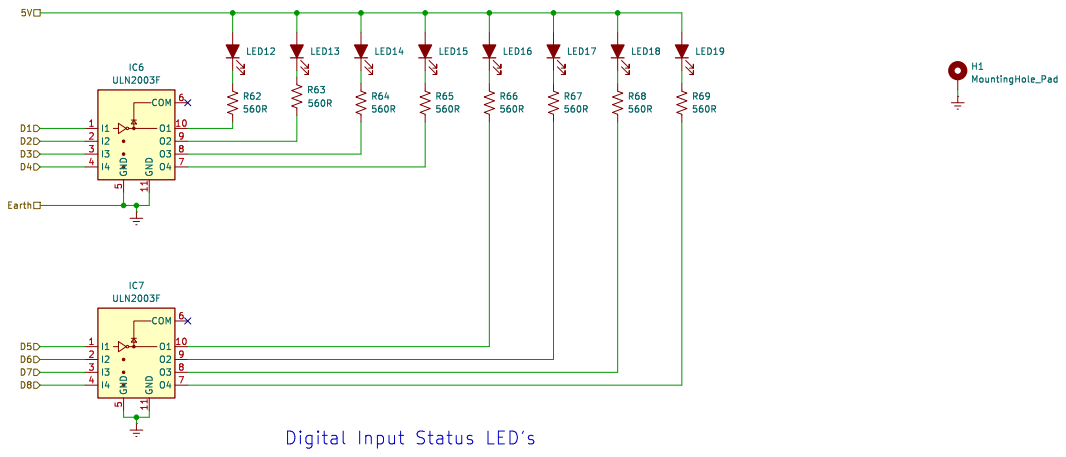
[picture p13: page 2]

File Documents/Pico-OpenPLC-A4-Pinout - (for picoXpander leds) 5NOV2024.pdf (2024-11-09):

# Raspberry Pi Pico

# Pinout for OpenPLC

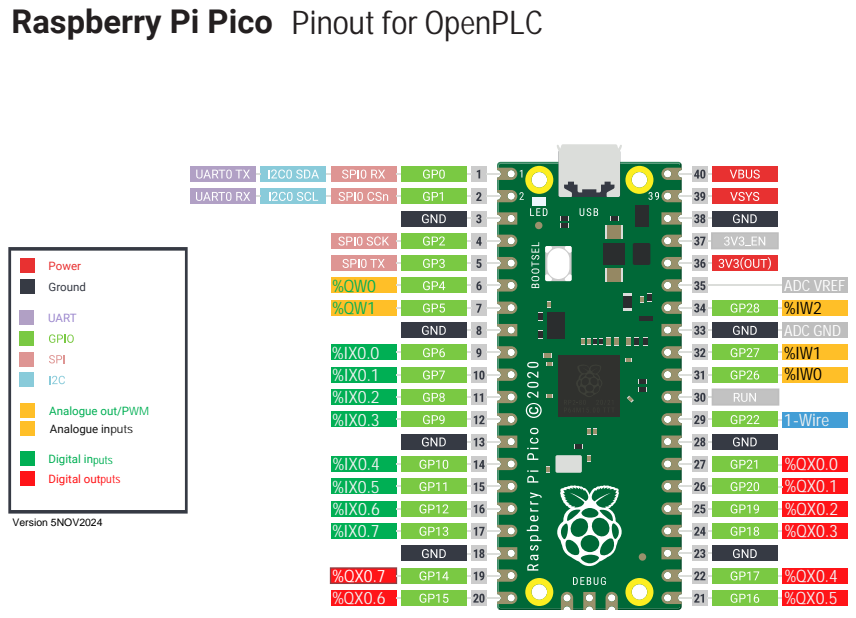
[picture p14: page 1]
Power Ground; UART; puts; 1-Wire; Digital outputs; %IW2 ADC GND; ADC VREF; Version 5NOV2024; Digital in

Analogue out/PWM
Analogue inputs

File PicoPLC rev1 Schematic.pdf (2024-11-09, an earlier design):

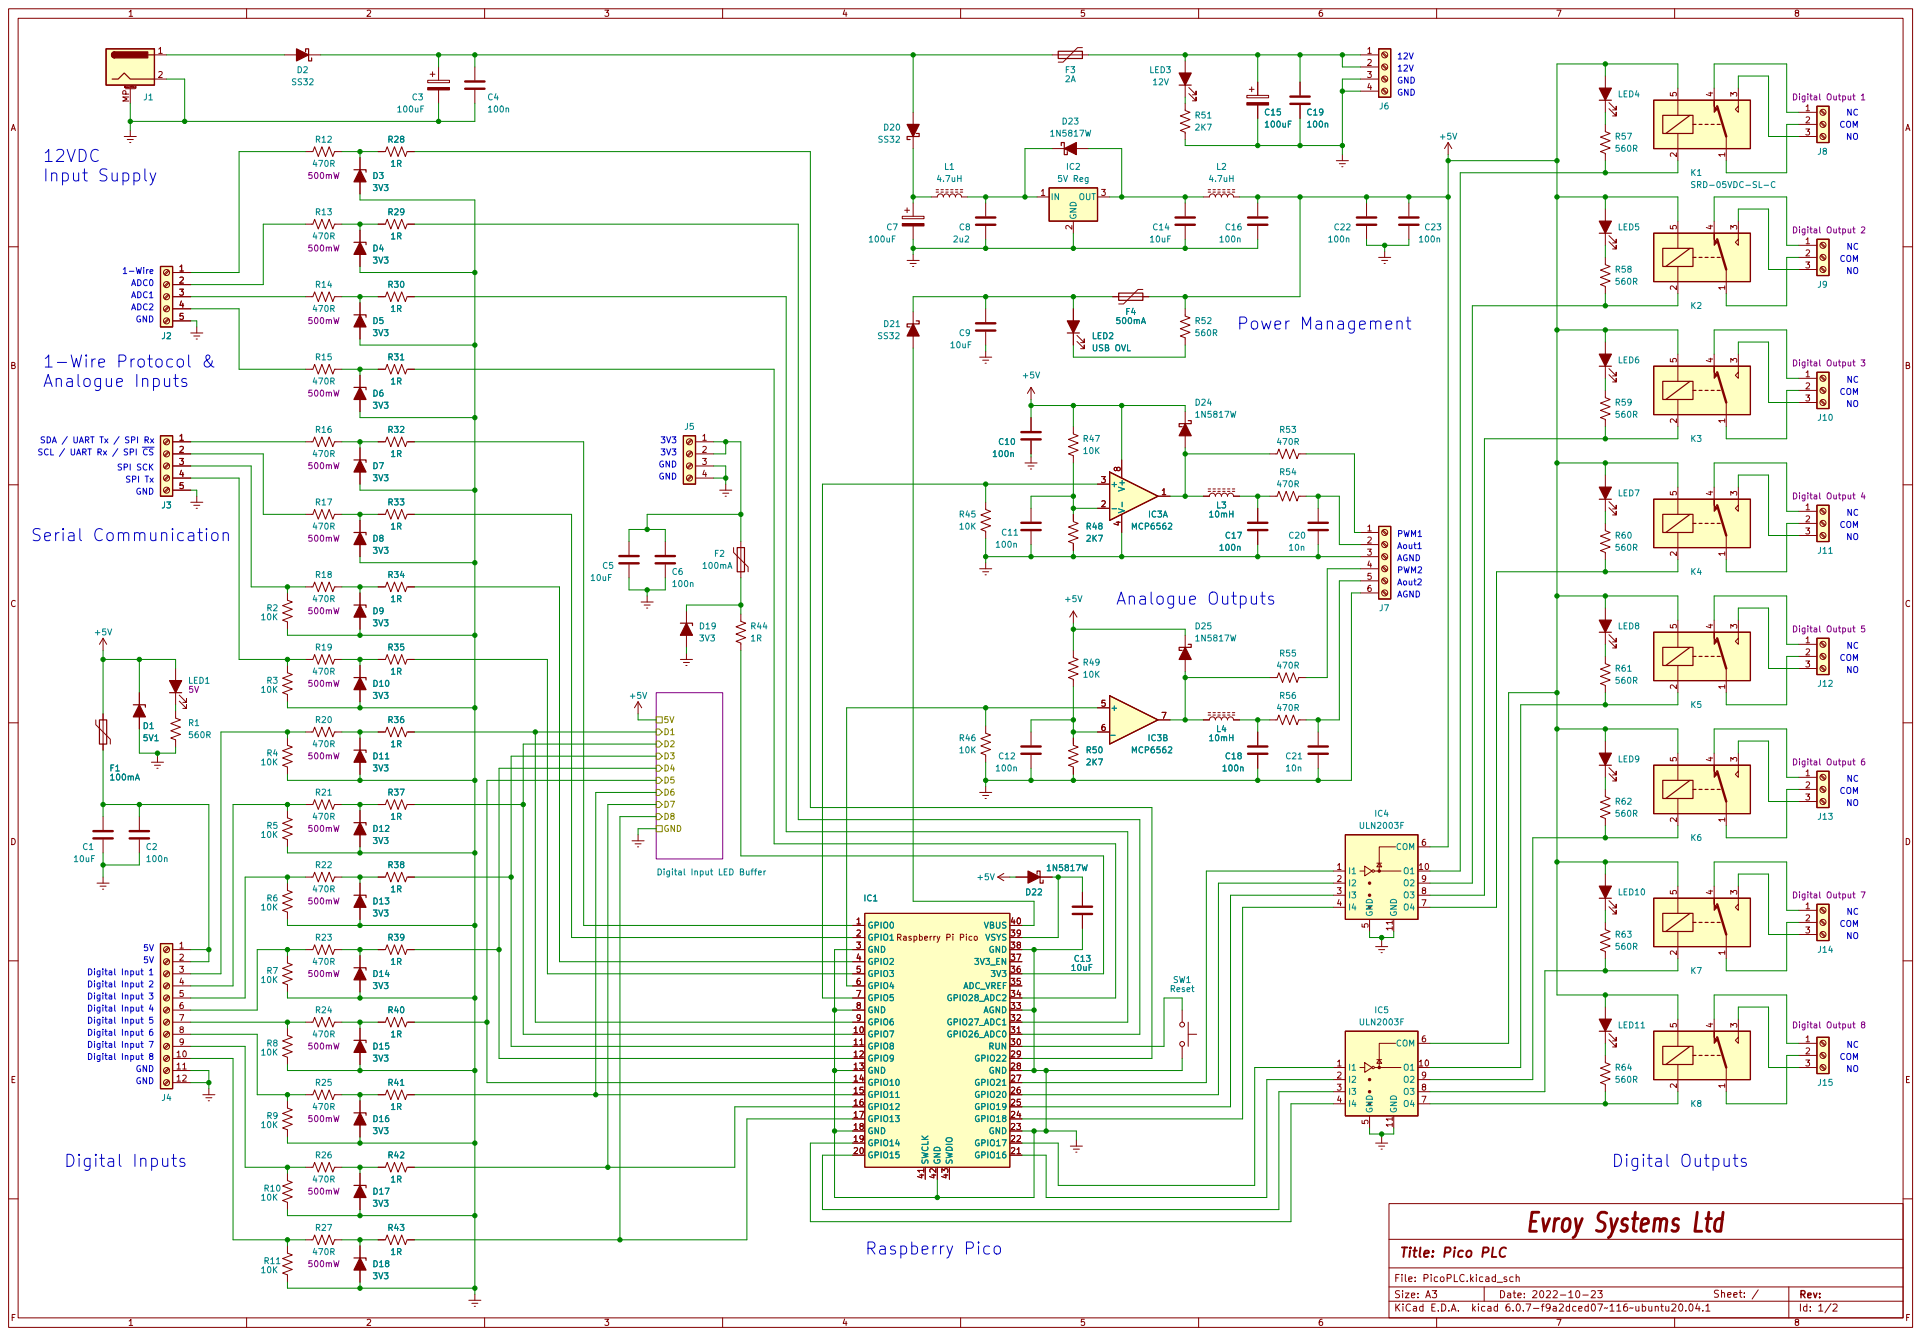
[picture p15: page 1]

NC GND GND GND 1-Wire Protocol &

Id: 1/2 Evroy Systems Ltd

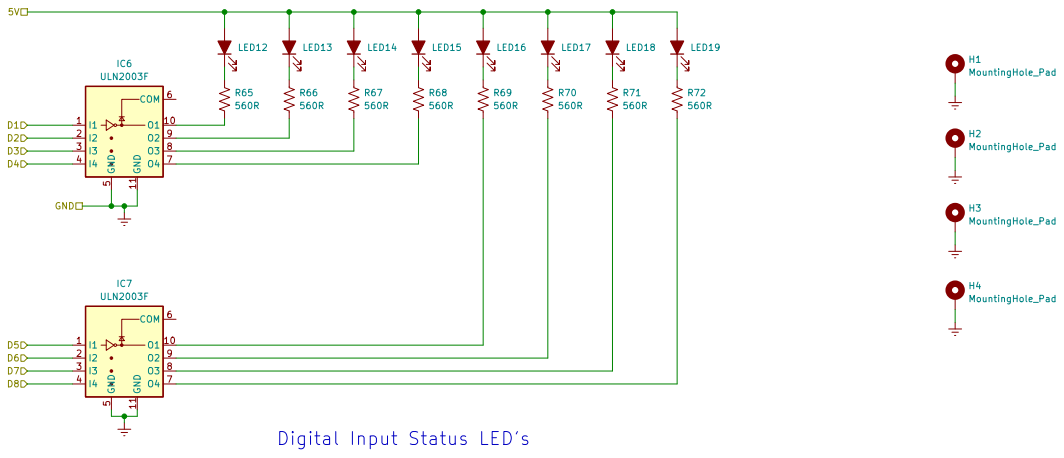
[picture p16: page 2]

Id: 2/2 Evroy Systems Ltd

Title: PicoPLC - Digital Input LED (Buffer)

Sheet: /Digital Input LED Buffer/

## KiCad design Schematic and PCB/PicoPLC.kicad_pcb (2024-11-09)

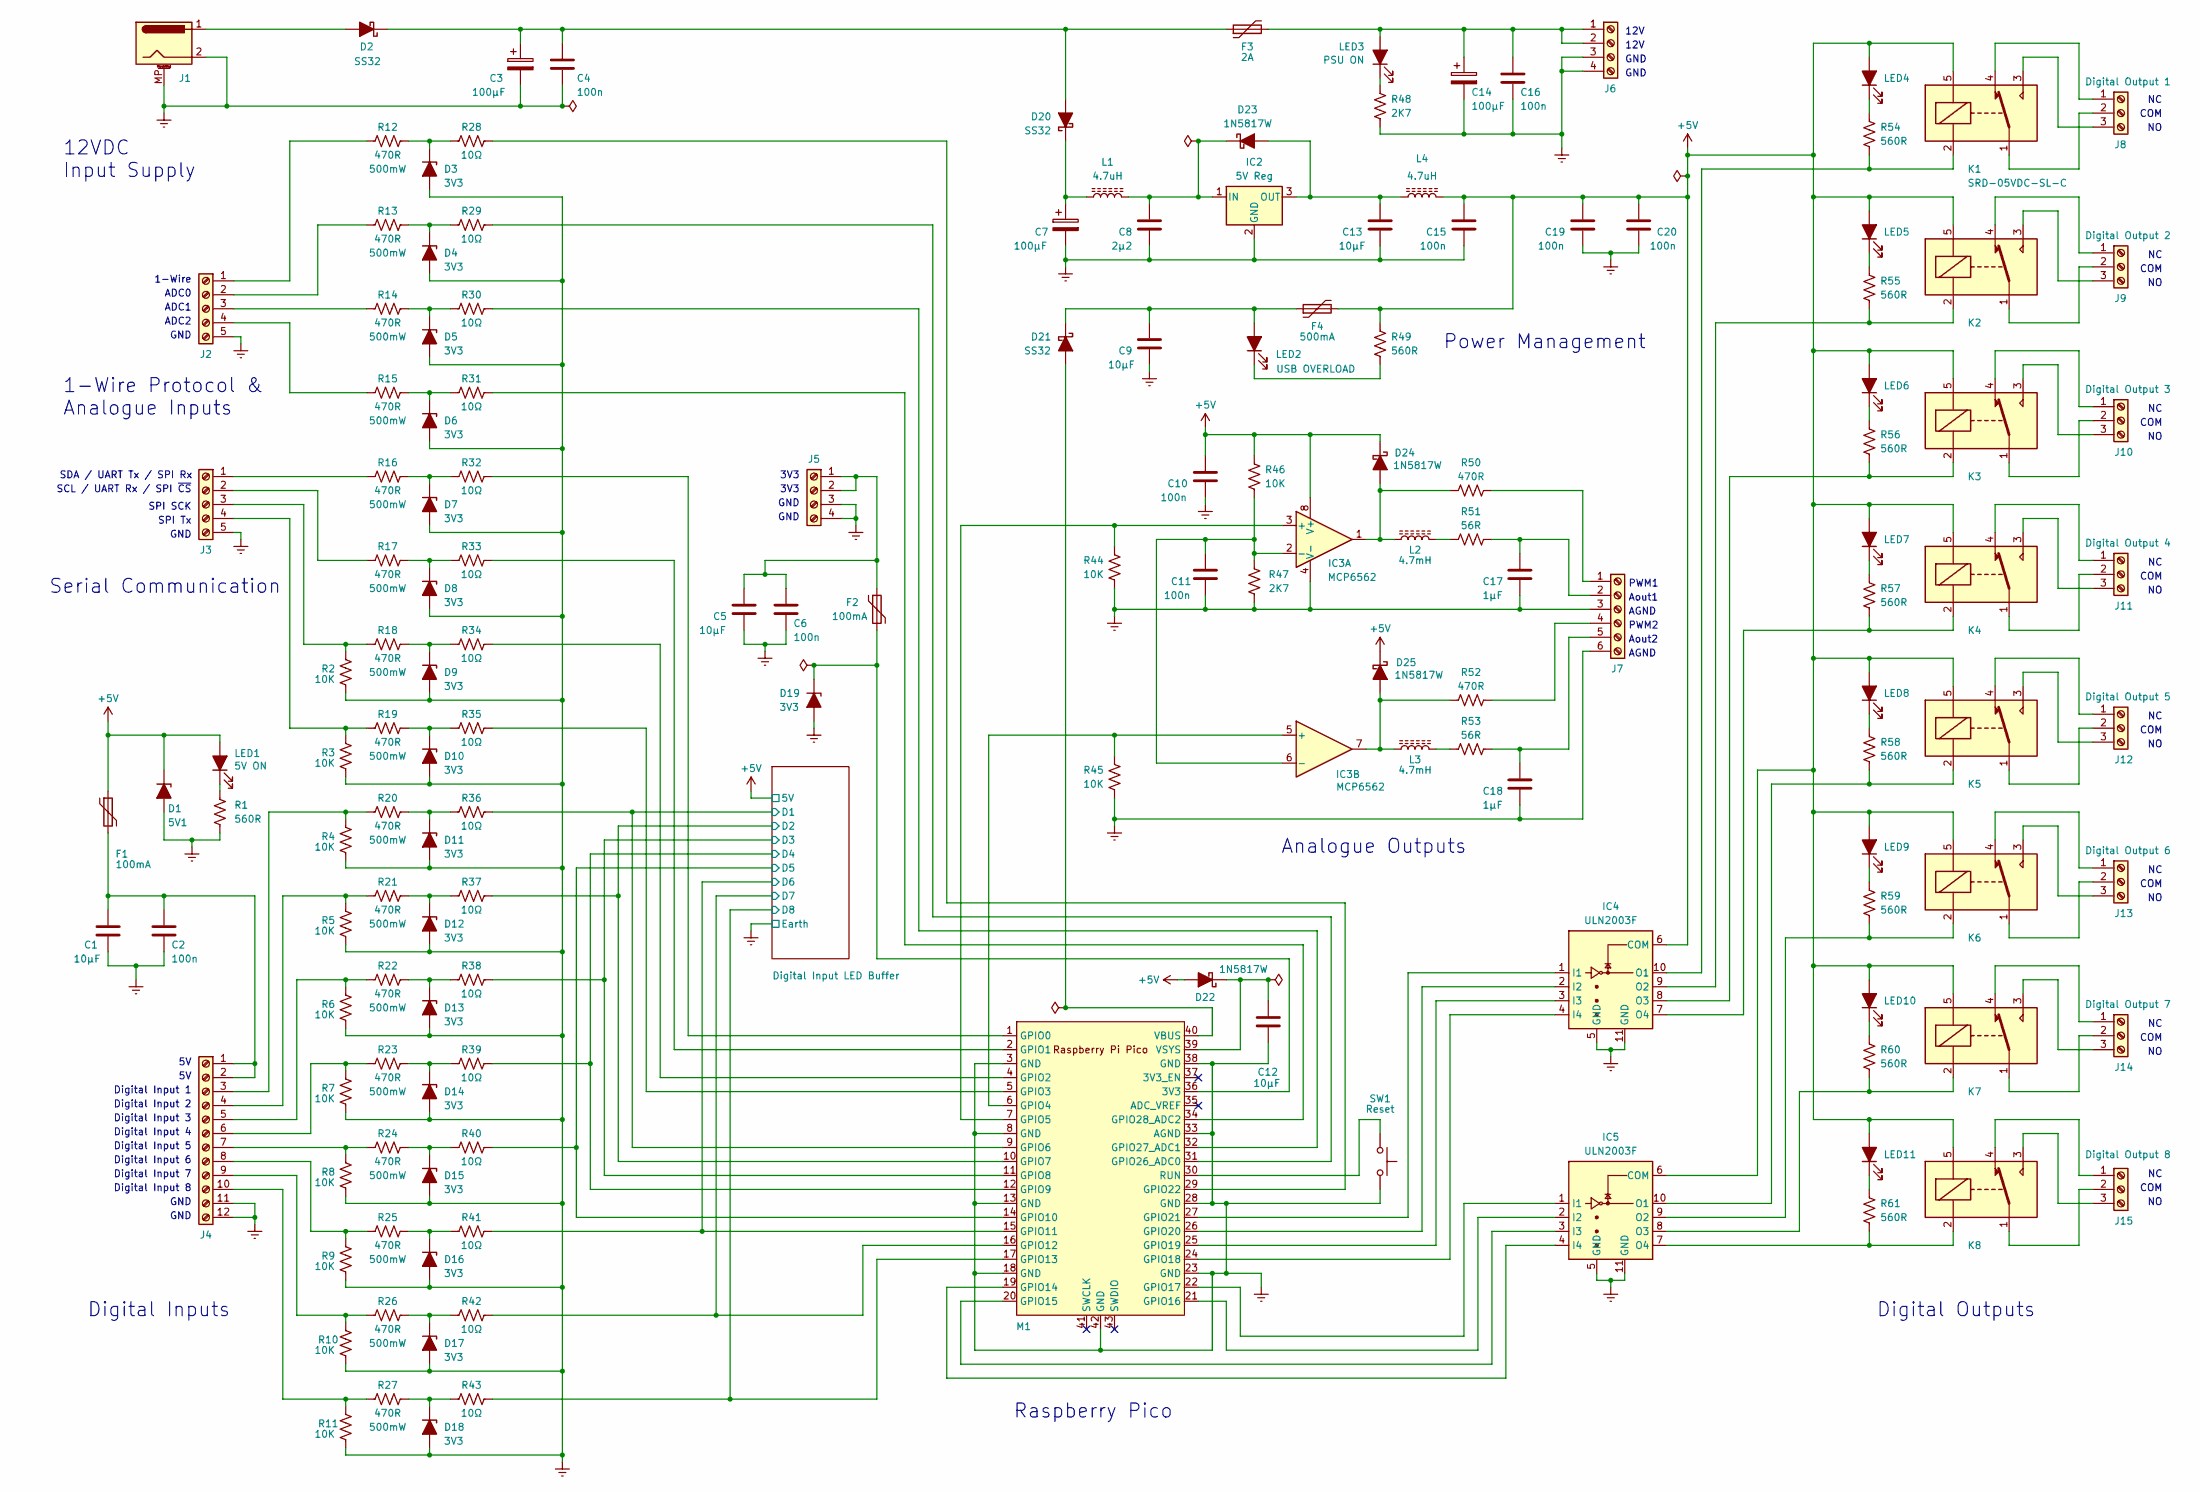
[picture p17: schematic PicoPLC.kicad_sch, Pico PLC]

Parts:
C1, C5, C9, C12, C13: 10µF; C_1206_3216Metric
C2, C4, C6, C10, C11, C15, C16, C19, C20: 100n; C_0805_2012Metric
C3, C7, C14: 100µF; CP_Elec_6.3x7.7
C8: 2µ2; C_0805_2012Metric
C17, C18: 1µF; C_0805_2012Metric
D1: 5V1; D_SOD-123
D2, D20, D21: SS32; D_SMA
D3, D4, D5, D6, D7, D8, D9, D10, D11, D12, D13, D14, D15, D16, D17, D18, D19: 3V3; D_SOD-123
D22, D23, D24, D25: 1N5817W; D_0805_2012Metric
F1, F2: 100mA; Fuse_0805_2012Metric
F3: 2A; Fuse_0805_2012Metric
F4: 500mA; Fuse_0805_2012Metric
IC2: 5V Reg; Converter_DCDC_RECOM_R-78E-0.5_THT
IC3: MCP6562; MSOP-8_3x3mm_P0.65mm
IC4, IC5: ULN2003F; DFN-10-1EP_3x3mm_P0.5mm_EP1.65x2.38mm
J1: 2.1/5.5mm Jack; BarrelJack_CUI_PJ-063AH_Horizontal
J2, J3: Screw_Terminal_01x05; Terminal_KF142V_Spring_5.08mm_V_5Pole
J4: Screw_Terminal_01x12; Terminal_KF142V_Spring_5.08mm_V_12Pole
J5, J6: Screw_Terminal_01x04; Terminal_KF142V_Spring_5.08mm_V_4Pole
J7: Screw_Terminal_01x06; Terminal_KF142V_Spring_5.08mm_V_6Pole
J8, J9, J10, J11, J12, J13, J14, J15: Screw_Terminal_01x03; Terminal_KF142V_Spring_5.08mm_V_3Pole
K1, K2, K3, K4, K5, K6, K7, K8: SRD-05VDC-SL-C; Relay_SPDT_SANYOU_SRD_Series_Form_C
L1, L4: 4.7uH; IND_Bourns_SRN5020; Part SRN5020TA-5R6M
L2, L3: 4.7mH; IND_Bourns_SDR0503
LED1, LED4, LED5, LED6, LED7, LED8, LED9, LED10, LED11: LED_Filled; LED_0805_2012Metric
LED2: USB OVERLOAD; LED_0805_2012Metric
LED3: PSU ON; LED_0805_2012Metric
M1: Pico; RPi_Pico_SMD_TH
R1, R49, R54, R55, R56, R57, R58, R59, R60, R61: 560R; R_0805_2012Metric
R2, R3, R4, R5, R6, R7, R8, R9, R10, R11, R44, R45, R46: 10K; R_0805_2012Metric
R12, R13, R14, R15, R16, R17, R18, R19, R20, R21, R22, R23, R24, R25, R26, R27, R50, R52: 470R; R_0805_2012Metric
R28, R29, R30, R31, R32, R33, R34, R35, R36, R37, R38, R39, R40, R41, R42, R43: 10Ω; R_0805_2012Metric
R47, R48: 2K7; R_0805_2012Metric
R51, R53: 56R; R_0805_2012Metric
SW1: Reset; SW_Tactile_SPST_Angled_PTS645Vx58-2LFS

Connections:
+5V: C10.1, C15.1, C19.1, C20.1, D1.1 (K), D22.2 (A), D24.1 (K), D25.1 (K), F1.1, F4.2, IC3.8 (V+), IC4.6 (COM), IC5.6 (COM), K1.5, K2.5, K3.5, K4.5, K5.5, K6.5, K7.5, K8.5, L4.2, LED1.2 (A), LED4.2 (A), LED5.2 (A), LED6.2 (A), LED7.2 (A), LED8.2 (A), LED9.2 (A), LED10.2 (A), LED11.2 (A), R46.2, R49.1; also elsewhere on the board
/Digital Input LED Buffer/D1: M1.9 (GPIO6), R36.2; also elsewhere on the board
/Digital Input LED Buffer/D2: M1.10 (GPIO7), R37.2; also elsewhere on the board
/Digital Input LED Buffer/D3: M1.11 (GPIO8), R38.2; also elsewhere on the board
/Digital Input LED Buffer/D4: M1.12 (GPIO9), R39.2; also elsewhere on the board
/Digital Input LED Buffer/D5: M1.14 (GPIO10), R40.2; also elsewhere on the board
/Digital Input LED Buffer/D6: M1.15 (GPIO11), R41.2; also elsewhere on the board
/Digital Input LED Buffer/D7: M1.16 (GPIO12), R42.2; also elsewhere on the board
/Digital Input LED Buffer/D8: M1.17 (GPIO13), R43.2; also elsewhere on the board
Earth: C1.2, C2.2, C3.2, C4.2, C5.2, C6.2, C7.2, C8.2, C9.2, C10.2, C11.2, C12.2, C13.2, C14.2, C15.2, C16.2, C17.2, C18.2, C19.2, C20.2, D1.2 (A), D3.2 (A), D4.2 (A), D5.2 (A), D6.2 (A), D7.2 (A), D8.2 (A), D9.2 (A), D10.2 (A), D11.2 (A), D12.2 (A), D13.2 (A), D14.2 (A), D15.2 (A), D16.2 (A), D17.2 (A), D18.2 (A), D19.2 (A), IC2.2 (GND), IC3.4 (V-), IC4.5 (GND), IC4.11 (GND), IC5.5 (GND), IC5.11 (GND), J1.2, J1.MP (MountPin), J2.5, J3.5, J4.11, J4.12, J5.3, J5.4, J6.3, J6.4, J7.3, J7.6, M1.3 (GND), M1.8 (GND), M1.13 (GND), M1.18 (GND), M1.23 (GND), M1.28 (GND), M1.33 (AGND), M1.38 (GND), M1.42 (GND), R1.2, R2.2, R3.2, R4.2, R5.2, R6.2, R7.2, R8.2, R9.2, R10.2, R11.2, R44.1, R45.1, R47.1, R48.2, SW1.2; also elsewhere on the board
unnamed: D2.2 (A), J1.1
unnamed: C3.1, C4.1, D2.1 (K), D20.2 (A), F3.1
unnamed: D3.1 (K), R12.2, R28.1
unnamed: D4.1 (K), R13.2, R29.1
unnamed: D5.1 (K), R14.2, R30.1
unnamed: D6.1 (K), R15.2, R31.1
unnamed: D7.1 (K), R16.2, R32.1
unnamed: D8.1 (K), R17.2, R33.1
unnamed: D9.1 (K), R18.2, R34.1
unnamed: D10.1 (K), R19.2, R35.1
unnamed: D11.1 (K), R20.2, R36.1
unnamed: D12.1 (K), R21.2, R37.1
unnamed: D13.1 (K), R22.2, R38.1
unnamed: D14.1 (K), R23.2, R39.1
unnamed: D15.1 (K), R24.2, R40.1
unnamed: D16.1 (K), R25.2, R41.1
unnamed: D17.1 (K), R26.2, R42.1
unnamed: D18.1 (K), R27.2, R43.1
unnamed: D19.1 (K), F2.2, M1.36 (3V3)
unnamed: C7.1, D20.1 (K), L1.1
unnamed: D21.2 (A), M1.40 (VBUS)
unnamed: C9.1, D21.1 (K), F4.1, LED2.2 (A)
unnamed: C12.1, D22.1 (K), M1.39 (VSYS)
unnamed: C13.1, D23.2 (A), IC2.3 (OUT), L4.1
unnamed: C8.1, D23.1 (K), IC2.1 (IN), L1.2
unnamed: D24.2 (A), IC3.1, L2.1, R50.1
unnamed: D25.2 (A), IC3.7, L3.1, R52.1
unnamed: IC3.3 (+), M1.7 (GPIO5), R44.2
unnamed: C11.1, IC3.2 (-), IC3.6 (-), R46.1, R47.2
unnamed: IC3.5 (+), M1.6 (GPIO4), R45.2
unnamed: IC4.1 (I1), M1.27 (GPIO21)
unnamed: IC4.2 (I2), M1.26 (GPIO20)
unnamed: IC4.3 (I3), M1.25 (GPIO19)
unnamed: IC4.4 (I4), M1.24 (GPIO18)
unnamed: IC4.10 (O1), K1.2, R54.2
unnamed: IC4.9 (O2), K2.2, R55.2
unnamed: IC4.8 (O3), K3.2, R56.2
unnamed: IC4.7 (O4), K4.2, R57.2
unnamed: IC5.1 (I1), M1.22 (GPIO17)
unnamed: IC5.2 (I2), M1.21 (GPIO16)
unnamed: IC5.3 (I3), M1.20 (GPIO15)
unnamed: IC5.4 (I4), M1.19 (GPIO14)
unnamed: IC5.10 (O1), K5.2, R58.2
unnamed: IC5.9 (O2), K6.2, R59.2
unnamed: IC5.8 (O3), K7.2, R60.2
unnamed: IC5.7 (O4), K8.2, R61.2
unnamed: J2.1, R12.1
unnamed: J2.2, R13.1
unnamed: J2.3, R14.1
unnamed: J2.4, R15.1
unnamed: J3.1, R16.1
unnamed: J3.2, R17.1
unnamed: J3.3, R2.1, R18.1
unnamed: J3.4, R3.1, R19.1
unnamed: C1.1, C2.1, F1.2, J4.1, J4.2
unnamed: J4.3, R4.1, R20.1
unnamed: J4.4, R5.1, R21.1
unnamed: J4.5, R6.1, R22.1
unnamed: J4.6, R7.1, R23.1
unnamed: J4.7, R8.1, R24.1
unnamed: J4.8, R9.1, R25.1
unnamed: J4.9, R10.1, R26.1
unnamed: J4.10, R11.1, R27.1
unnamed: C5.1, C6.1, F2.1, J5.1, J5.2
unnamed: C14.1, C16.1, F3.2, J6.1, J6.2, LED3.2 (A)
unnamed: J7.1, R50.2
unnamed: C17.1, J7.2, R51.1
unnamed: J7.4, R52.2
unnamed: C18.1, J7.5, R53.1
unnamed: J8.1, K1.4
unnamed: J8.2, K1.1
unnamed: J8.3, K1.3
unnamed: J9.1, K2.4
unnamed: J9.2, K2.1
unnamed: J9.3, K2.3
unnamed: J10.1, K3.4
unnamed: J10.2, K3.1
unnamed: J10.3, K3.3
unnamed: J11.1, K4.4
unnamed: J11.2, K4.1
unnamed: J11.3, K4.3
unnamed: J12.1, K5.4
unnamed: J12.2, K5.1
unnamed: J12.3, K5.3
unnamed: J13.1, K6.4
unnamed: J13.2, K6.1
unnamed: J13.3, K6.3
unnamed: J14.1, K7.4
unnamed: J14.2, K7.1
unnamed: J14.3, K7.3
unnamed: J15.1, K8.4
unnamed: J15.2, K8.1
unnamed: J15.3, K8.3
unnamed: L2.2, R51.2
unnamed: L3.2, R53.2
unnamed: LED1.1 (K), R1.1
unnamed: LED2.1 (K), R49.2
unnamed: LED3.1 (K), R48.1
unnamed: LED4.1 (K), R54.1
unnamed: LED5.1 (K), R55.1
unnamed: LED6.1 (K), R56.1
unnamed: LED7.1 (K), R57.1
unnamed: LED8.1 (K), R58.1
unnamed: LED9.1 (K), R59.1
unnamed: LED10.1 (K), R60.1
unnamed: LED11.1 (K), R61.1
unnamed: M1.1 (GPIO0), R32.2
unnamed: M1.2 (GPIO1), R33.2
unnamed: M1.4 (GPIO2), R34.2
unnamed: M1.5 (GPIO3), R35.2
unnamed: M1.29 (GPIO22), R28.2
unnamed: M1.31 (GPIO26_ADC0), R29.2
unnamed: M1.32 (GPIO27_ADC1), R30.2
unnamed: M1.34 (GPIO28_ADC2), R31.2
unnamed: M1.30 (RUN), SW1.1

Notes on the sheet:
Aout1
GND
COM
SPI SCK
ADC1
Analogue Outputs
Digital Input 7
SPI Tx
ADC0
3V3
12V
Digital Input 4
Digital Outputs
Digital Input 8
Power Management
Digital Input 5
Digital Input 6
12VDC Input Supply
1-Wire
1-Wire Protocol & Analogue Inputs
Digital Input 2
PWM1
Digital Input 1
ADC2
AGND
Serial Communication
SCL / UART Rx / SPI ~{CS}
SDA / UART Tx / SPI Rx
Digital Input 3
Digital Inputs
Aout2
PWM2
Raspberry Pico

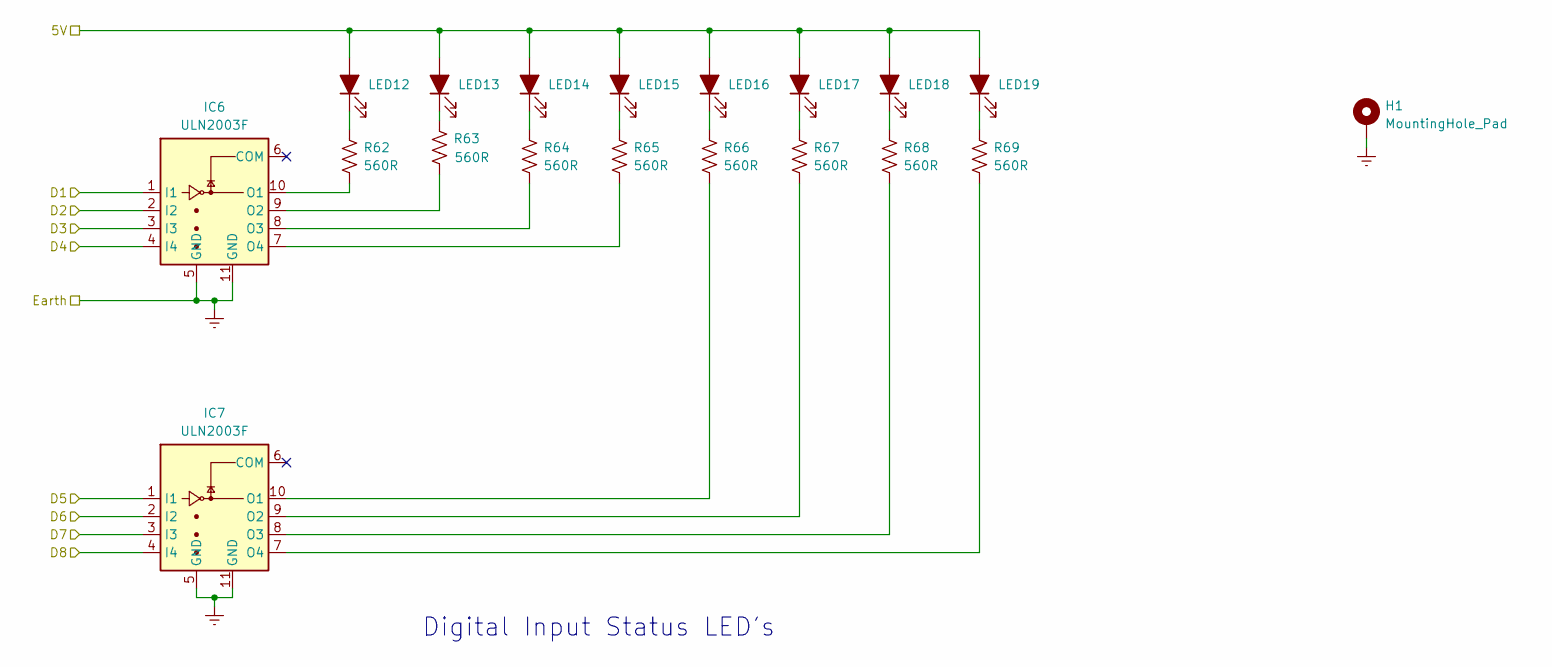
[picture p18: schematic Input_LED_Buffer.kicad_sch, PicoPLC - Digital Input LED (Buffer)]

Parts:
H1: MountingHole_Pad; MountingHole_3mm_Pad
IC6, IC7: ULN2003F; DFN-10-1EP_3x3mm_P0.5mm_EP1.65x2.38mm
LED12, LED13, LED14, LED15, LED16, LED17, LED18, LED19: LED_Filled; LED_0805_2012Metric
R62, R63, R64, R65, R66, R67, R68, R69: 560R; R_0805_2012Metric

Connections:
+5V: LED12.2 (A), LED13.2 (A), LED14.2 (A), LED15.2 (A), LED16.2 (A), LED17.2 (A), LED18.2 (A), LED19.2 (A); also elsewhere on the board
/Digital Input LED Buffer/D1: IC6.1 (I1); also elsewhere on the board
/Digital Input LED Buffer/D2: IC6.2 (I2); also elsewhere on the board
/Digital Input LED Buffer/D3: IC6.3 (I3); also elsewhere on the board
/Digital Input LED Buffer/D4: IC6.4 (I4); also elsewhere on the board
/Digital Input LED Buffer/D5: IC7.1 (I1); also elsewhere on the board
/Digital Input LED Buffer/D6: IC7.2 (I2); also elsewhere on the board
/Digital Input LED Buffer/D7: IC7.3 (I3); also elsewhere on the board
/Digital Input LED Buffer/D8: IC7.4 (I4); also elsewhere on the board
Earth: H1.1, IC6.5 (GND), IC6.11 (GND), IC7.5 (GND), IC7.11 (GND); also elsewhere on the board
unnamed: IC6.10 (O1), R62.2
unnamed: IC6.9 (O2), R63.2
unnamed: IC6.8 (O3), R64.2
unnamed: IC6.7 (O4), R65.2
unnamed: IC7.10 (O1), R66.2
unnamed: IC7.9 (O2), R67.2
unnamed: IC7.8 (O3), R68.2
unnamed: IC7.7 (O4), R69.2
unnamed: LED12.1 (K), R62.1
unnamed: LED13.1 (K), R63.1
unnamed: LED14.1 (K), R64.1
unnamed: LED15.1 (K), R65.1
unnamed: LED16.1 (K), R66.1
unnamed: LED17.1 (K), R67.1
unnamed: LED18.1 (K), R68.1
unnamed: LED19.1 (K), R69.1

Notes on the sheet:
Digital Input Status LED's

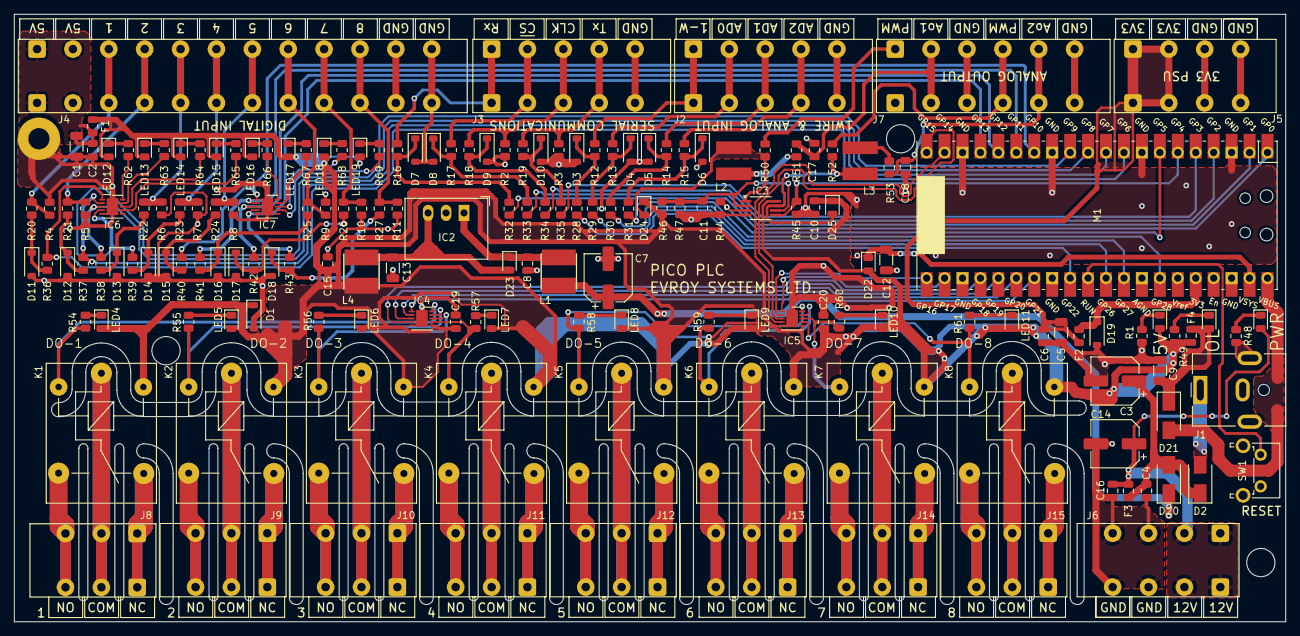
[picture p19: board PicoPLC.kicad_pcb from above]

Board: 2 copper layers, 180.0 x 86.0 mm, 173 parts (0 on the bottom side), 141 nets.

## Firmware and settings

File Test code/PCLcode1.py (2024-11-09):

# basic template for using the Pico as a Programmable Logic controller
import time

# Pico digital I/O mapping file as per the diagram Pico-OpenPLC-A4-Pinout.pdf
import iomapping as IO

# roll through the outputs and toggle the respective output


def pollOut1(delay):
    for i in range(8):
        port = f"IO.QX{i}"
        fnc = eval(port)
        fnc.value = True
        time.sleep(delay)
        fnc.value = False

# roll through the outputs and toggle the respective output


def pollOut(delay):

    IO.QX0.value = True
    time.sleep(delay)
    IO.QX0.value = False

    IO.QX1.value = True
    time.sleep(delay)
    IO.QX1.value = False

    IO.QX2.value = True
    time.sleep(delay)
    IO.QX2.value = False

    IO.QX3.value = True
    time.sleep(delay)
    IO.QX3.value = False

    IO.QX4.value = True
    time.sleep(delay)
    IO.QX4.value = False

    IO.QX5.value = True
    time.sleep(delay)
    IO.QX5.value = False

    IO.QX6.value = True
    time.sleep(delay)
    IO.QX6.value = False

    IO.QX7.value = True
    time.sleep(delay)
    IO.QX7.value = False

# scan inputs and toggle the respective output twice


def pollIn():
    toggle = False
    # scan through the inputs
    for i in range(8):
        port = f"IO.IX{i}"
        fnc = eval(port)
        # if the input is high toggle the out twice
        if fnc.value:
            port = f"IO.QX{i}"
            fnc = eval(port)
            fnc.value = True
            time.sleep(0.2)
            fnc.value = False
            fnc.value = True
            time.sleep(0.2)
            fnc.value = False
            toggle = True
            time.sleep(0.2)

    return toggle


# ========== main ==========
flag = True
while True:

    # keep scanning whilst there is an input
    flag = pollIn()

    if not flag:
        # pollOut(0.2)
        pollOut1(0.1)

# these lines used to confirm code is running in the loop
    IO.LED.value = not IO.LED.value
    time.sleep(1.0)

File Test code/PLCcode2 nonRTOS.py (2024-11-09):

# basic template for using the Pico as a Programmable Logic controller
import time
import struct
from microcontroller import cpu
import usb_cdc
import simpleio
import adafruit_ssd1306
import adafruit_dht
#from adafruit_motor import servo

# Pico digital I/O mapping file as per the diagram Pico-OpenPLC-A4-Pinout.pdf
import iomapping as IO

# uart = usb_cdc.console
uart = usb_cdc.data

# attach an oled = adafruit_ssd1306.SSD1306_I2C(128, Y, IO.I2C, addr=0x3C)
# change the 32 to 64 for the larger oled
# YRES 32 for the smaller thin OLED display
# YRES 64 for the larger square OLED display
oled = adafruit_ssd1306.SSD1306_I2C(128, 64,IO.I2C)

# attach dht to the single wire on GPIO22
dht = adafruit_dht.DHT11(IO.ONEWIRE)

# roll through the outputs and toggle the respective output
def pollOut(delay):
    for i in range(8):
        port = f"IO.QX{i}"
        fnc = eval(port)
        fnc.value = True
        time.sleep(delay)
        fnc.value = False

def pollIn():
# scan inputs and toggle the respective output twice
    toggle = False
    # scan through the inputs
    for i in range(8):
        port = f"IO.IX{i}"
        fnc = eval(port)
        # if the input is high toggle the out twice
        if fnc.value:
            port = f"IO.QX{i}"
            fnc = eval(port)
            fnc.value = True
            time.sleep(0.5)
            fnc.value = False
            toggle = True
            time.sleep(0.2)
    return toggle

def dispOLED():
    oled.text("Ambient T & H", 0, 0, 1)
    txt = ""   
   #txt = "T:%d, H:%d, C:%.2f"% (dht.temperature, dht.humidity,cpu.temperature)
    try:
        txt = f"T:{dht.temperature}', H:{dht.humidity}%, C:{cpu.temperature:.0f}'"
    except:
        return
    time.sleep(0.02)
    oled.text(txt, 0, 10, 1)

def sendDHT():
    try:
      #pass
        buffer = struct.pack("<iii",int(dht.humidity), dht.temperature, int(cpu.temperature))        
        uart.write(buffer)
    except RuntimeError as error:
        print("Transmission or data error")
        return
    except Exception as error:
        dht.exit()
        raise error

def doAnalog():
    value1 = IO.IW0.value * (IO.IW0.reference_voltage /65535)
    value2 = IO.IW1.value * (IO.IW1.reference_voltage /65535)
    dc1 = int(simpleio.map_range(value1, 0, 2.45 , 0, 65535))
    dc2 = int(simpleio.map_range(value2, 0, 2.45 , 0, 65535))
    v = f'voltage: {value1:.2f},{value2:.2f}V'
    dc = f'dc: {dc1},{dc2}'
    print(v,dc)
    #servo.angle = simpleio.map_range(value, 0, 2.5, 0, 100)
    IO.QW0.duty_cycle = dc1
    IO.QW1.duty_cycle = dc2
    oled.text(v,0,20,1)
    oled.text(dc,0,30,1)
    
# ========== main ==========
flag = True
while True:
    oled.fill(False)  
    dispOLED()
# keep scanning whilst there is an input
    flag = pollIn()

    if not flag:
        pollOut(0.1)
    
    sendDHT()
    doAnalog()
    oled.show()
    
# these lines used to confirm code is running in the loop
    IO.LED.value = not IO.LED.value
    time.sleep(0.02)
    

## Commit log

2024-11-09 Initial repo
    [Input_LED_Buffer.kicad_sch, PicoPLC PCB BOM.ods, PicoPLC PCB BOM.xlsx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]
2024-11-14 Added some PWM testing
